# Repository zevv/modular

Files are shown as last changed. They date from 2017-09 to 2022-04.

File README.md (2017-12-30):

This repo contains the electronic design files and firmware for an
analog/digital hybrid modular synthesizer system. The synth will be built from
a collection of separate modules which can be connected (patched) like a
traditional modular synth. The modules contain a fast CPU and an audio codec
and perform all work in the digital domain. The same PCB design is used in all
modules, and the firmware will make each module behave as a different function
like oscillators, filters, wave shapers, delay, reverb, etc.

Engineering log with some pictures can be found here: http://zevv.nl/play/modular/

Some specs for the module so far:

* 204Mhz dual core ARM Cortex M4/M0
* 4 audio outputs 10v peak-to-peak at 10kΩ, 96kHz/24bit
* 4 audio inputs 10v peak-to-peak at 330Ω, 96kHz/24bit
* 8 generic inputs 10v peak-to-peak at 10kΩ, 12kHz/10 bit
* 12V power supply, internally split into +5/-5 volts 

My primary goal is to make a working setup for my personal use. However, if I'm
happy enough with the results and other people are interested, I might consider
manufacturing and selling modules at a small scale.

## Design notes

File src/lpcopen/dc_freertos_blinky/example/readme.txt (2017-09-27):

Blinky Example using Dual Core communication

Example description
This example blinks LED1 and LED2 at various rates, one of the LED
is turned on/off by M4 based on message received from M0. Meanwhile
M4 also sends blink message to M0 so that M0 core blinks the other LED.
LED1 will blink at the rate of 500ms/blink, LED2 will blink at the rate of
1s/blink.

This example is included by default in all other dual-core examples,
hence all the dual-core examples will blink LED1 and LED2.

*IMPORTANT NOTE:**
 
 M0 image boot failure will also cause (by default) LED2 to blink. This
 should not be confused with the Blinky task blinking the LED. The error
 blink will be at 20ms or 2s rate, the former rate indicates that the M0
 image loader code running on core-M4 could not locate a valid M0 image,
 whereas the latter rate indicates that a valid M0 image is found but its
 functionality is mutually exclusive with the functionalities of the image
 running in core-M4. In case of M0 boot error the blink will stop after 1
 minute.

Special connection requirements
   - Hitex LPC4350EVA-A4-2
      + LED1 is D10 (located below micro USB connector X9,*needs jumper JP3 closed**)
      + LED2 is RED of RGB LED
   - KEIL MCB4357
      + LED1 is PD_10 (located above push button P4_0)
      + LED2 is PD_11 (located next to LED1)
   - NGX Explorer4330
      + LED1 is D2 (Dull Green LED)
      + LED2 is D3 (Bright Blue LED)

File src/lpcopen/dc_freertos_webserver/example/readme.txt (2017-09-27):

HTTP server dual core example using lwIP ethernet stack

Example description
The LWIP HTTP Server example demonstrates the HTTP Server example using LWIP ethernet stack.
The HTTP server can be configured to run on any of the cores (M4 or M0).
The user should connect the board to the network by using the ethernet cable. The board will
get an IP address by using DHCP method. The use can access the HTTP Server by using a
web browser from the host PC.
If the USB Mass storage is compiled in the application (on either M0/M4 core), then it will
read the HTTP contents from USB Mass storage disk & provided to the user.
If the USB Mass storage is not compiled in the application (on either M0/M4 core), then the
default HTTP page will be displayed.
In FreeRTOS/uCOS-III configurations, the net_conn API interface will be used.
In stand-alone configuration, HTTPD interface will be used.

Special connection requirements
There are no special connection requirements for this example.

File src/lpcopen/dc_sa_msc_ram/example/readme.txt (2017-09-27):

This file contains a USB MSC RAM example using USB ROM Drivers.

Example description
The example shows how to use USBD ROM stack to creates a USB MSC example
that uses RAM.

Special connection requirements
Connect the USB cable between micro connector on board and to a host.
The example exposes part of internal SRAM as storage space.

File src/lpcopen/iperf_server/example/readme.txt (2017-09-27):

LWIP no-RTOS TCP Echo example

Example description
Welcome to the LWIP TCP Echo example using the raw API for standalone
without an RTOS) operation. This example shows how to use the raw API with
the LWIP contrib TCP Echo example using the 18xx/43xx LWIP MAC and PHY drivers.
The example shows how to handle PHY link monitoring and indicate to LWIP that
a ethernet cable is plugged in. It also shows how to manage input packet
handling and reclaim transmit pbufs once they are transmitted in the main
processing loop.

To use the example, Simply connect an ethernet cable to the board. The board
will acquire an IP address via DHCP and you can ping the board at it's IP
address. You can monitor network traffice to the board using a tool such as
wireshark at the boards MAC address.

Special connection requirements
There are no special connection requirements for this example.

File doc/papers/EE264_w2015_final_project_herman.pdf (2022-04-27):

# DSPFuzz A Guitar Distortion Pedal Using The Stanford DSP Sheild

Woody Herman
Center For Computer Research In Music And Acoustics Stanford University
Stanford, CA
Email: w.q.herman@gmail.com

Abstract—This project uses the Stanford DSP Sheild to implement a real time guitar distortion effects pedal. Presented here is a summary of the methods used, DSP concepts applied, and an analysis of what effects a distortion effect has on a signal.

I. INTRODUCTION

In live performance and in recording sessions, guitarists frequently alter the tone of their instrument using effects pedals, commonly referred to as stompboxes since the user engages the pedal with a foot swtich. One of the most widely used effects is the distortion, or overdrive, effect. This clips the signal of the guitar creating a unique distorted sound that can be heard on nearly every rock recording made since the 1950s. In its earliest from, distortion was implemented by driving the transistor or vacuum tube amplifiers used into cutoff. With the new prominence of digital recording and effects, many of the classic analog stompboxes have been implemented digitally with great effect. Distortion, however, remains firmly rooted in the analog domain. Because of the many nonlinearities present in these distortion effects, it has been hard to create pleasent sounding digital alternatives. Despite these issues, and because of the problems inherent in maintaining and designing analog equipment, developing quality digital versions would certainly be of great value. This project implements a simple and commonly used method for recreating distortion effects digitally.

II. OVERVIEW OF THE METHOD

A simple, commonly used technique for replicating the sound created by analog distortion pedals is to apply a predistortion filter, for controlling the input tone, follwed by up-sampling, applying the non-linearity, down sampling and finally another filter to control output tone. This technique is widley is used in industry and, if the tone filters are tuned properly and if the non-linearity is carefully chosen, can yeild sonically pleasing results. This method is primarily chosen for its compuational simplicity, many of the nonlinear functions (often called waveshaping functions) are polynomials relating input amplitude to output amplitude, and flexiblity to create a variety of sounds.

A. Waveshaping Functions
Choosing the waveshaping function that will clip the signal is a very subjective art, although there are several that have become very popular throughout the years. Generally, they all follow the same format. That is, they are non linear functions that relate input amplitude x to output amplitude y. Equations
(1) and (2) show two popular waveshaping functions.

y =

x
1 + |x|

(1)

y = x +

x

3
3

(2)

The functions above are written as they would be used for implementation in floating point systems. As will be shown later, fixed point arithmetic introdcues several new problems that make directly implementing these functions difficult if not impossible.

B. Tone Shaping Filters
Guitarists, and musicians in general, constantly talk about the tone of their instrument. The tone of an instrument in due in large part to the frequency response of that instrument. Because an electric guitar turns the vibration of its strings into electricity, we can apply any filter, analog or digital, that we might use in other applications. By boosting high frequencies we can make the guitar sound brighter, by boosting lower frequencies we can make the guitar sound fuller, or perhaps darker. What constitutes a good tone is highly subjective, but regardless of the result it is desireable to have some sort of filtering of the guitar signal in distortion effects. By applying a filter to the input and output signal of the effect, we can create custom tones or attempt to match the tone of famous analog effects.

III. RELATION TO COURSE TOPICS
Although the idea behind distortion is relatively simple, performing the operations digitally requires the use of a number of common and important digital signal processing theories. These include upsampling, digital filter design, analysis of our signal in the frequency domain, and fixed point arithmetic.

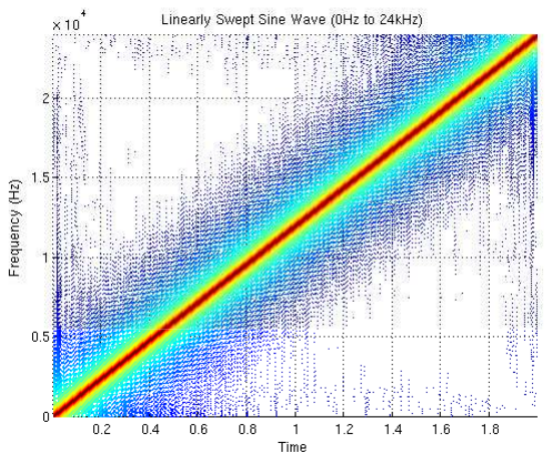
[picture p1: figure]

Fig. 1. Spectrogram of a chirp signal starting at dc and ending at 24kHz

A. Upsampling
As mentioned previously, implementing digital distortion requires the use of upsampling. This is because non linear functions, especially ones that clip the signal, introduce harmonics of the original frequency content. In distortion effects, when high gain is used, these harmonics can have audible amplitudes up to the 4th or 5th harmonic (that is 4 or 5 times the fundamental frequency). Because of this, we run the risk of our signal aliasing if a lot of distortion is applied. To counteract this aliasing, we upsample our signal to a much higher rate (8 and 16 are common factors used in industry) apply the non linearity and then down sample to the original rate. When used in conjunction with an interpolating and decimating filter, which can be the same filter since we are returning to the same sampling rate we started with, this blocks the aliased components while allowing for a natural expansion of harmonics in the audible range. This is important since the harmonics introduced by these clipping functions are an important part of the overall tone they give the guitar.
To illustrate this point, it is helpful to analyze the effects of clipping functions in the frequency domain using the DFT. Fig 1 shows a spectrogram of a chirp signal, a sine wave whose frequency increases linearly with time, that starts at dc and ends at the original nyquist frequency, 24kHz.
If we pass this chrip signal through a clipping function, then the effects of aliasing become apparent. Below is a figure showing the same chirp signal passed through a hard clipping function, where the signal is abruptly flattened at the maximum amplitude.
Fig. 2 is an exaggerated version of what might actually occur because the frequecny response of an electric guitar tends to roll off at higher frequencies. Nevertheless, aliasing is still audible when upsampling is not used. If upsampling is used in conjunction with an interpolating and decimating filter then we can remove the aliased components while preserving the desired harmonics that occur naturally in analog distortion devices.

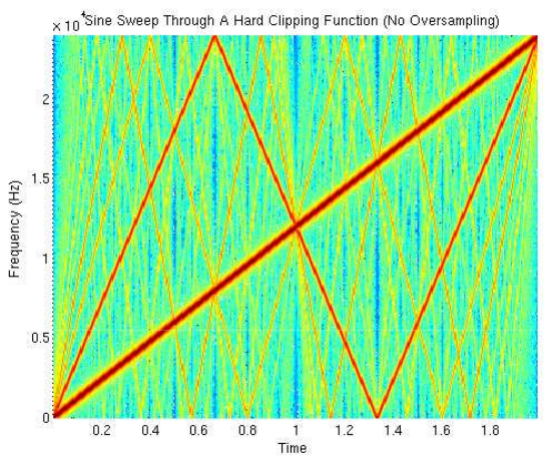
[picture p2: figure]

Fig. 2. Spectrogram of a chirp signal passed through a hard clipping function with no upsampling

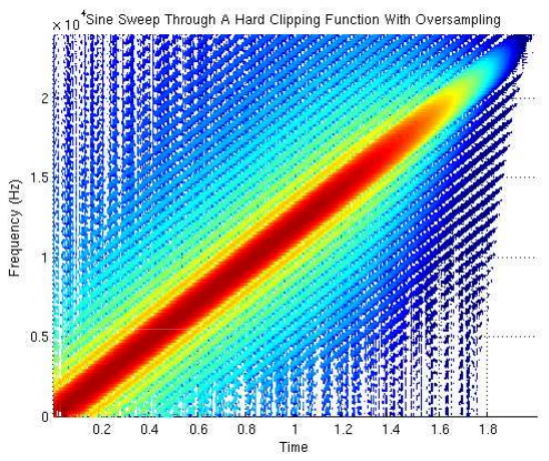
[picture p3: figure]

Fig. 3. Spectrogram of a chirp signal that has been upsampled by a factor of 8, filtered, clipped, filtered, and downsampled back to the original rate

Fig. 3 shows the same chirp signal passed through the same clipping function, but this time we have upsampled by a factor of 8 (using an interpolating filter whose design is described in subsequent sections), then applied the clipping function, then filtered the clipped signal with the same filter and downsampled back to the original rate. As can be seen in the plot, the aliased components have been removed but, as is desired, harmonics have been introduced to the signal. These harmonics are represented by the parallel bands in the spectrogram above and below the chirp signal. As mentioned before, these harmonics are very desireable since they help shape the tone of the disorted guitar signal. It should be noted that the magnitude of the chirp signal decreases as we approach nyquist. This, as will be shown later, is due to the fact that the filter used in upsampling and downsampling has a cutoff frequency below half the sampling rate.

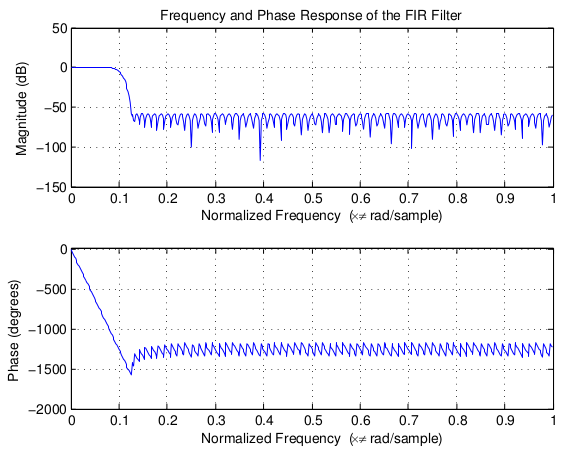
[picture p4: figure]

Fig. 4. Frequency response of the low pass filter used for up sampling and down sampling.

B. Filter Design

In order to properly implement the upsampling and downsampling required by digital distortion effects, we must design an interpolating filter that accomplishes several goals. First, as is always the case, it must remove the images of our spectrum created by sampling. Second, it must prevent aliasing caused by the non linear waveshaping function. Third, it must preserve as much of the original signal and added harmonics as possible. Lastly, it must be computationally efficient enough to be run in real time.
To accomplish the design criteria of the filter, the Parks-McLellan algorithm was used via MATLAB’s f irpm() function. Although a similar inerpolation and decimation filter could be acheived with a far lower order IIR filter, an FIR option is attractive for several reasons. Because the PM designed FIR filter would be linear phase, we know that no phase distortion would occur. Furthermore, the DSP Sheild has builtin functions in the DSP library that efficiently up sample and down sample using FIR filters. The library implementation of these functions would almost certainly be faster than anything written.
Figure 4 shows the frequency response of a 141 order Parks-McLellan designed filter. Because electric guitars typically have frequency responses that begin to roll off at a little over 10kHz we are able to have the filter pass band end at 15kHz with no real audible effects. This allows us to obtain a stop band gain of −60dB that begins at 24kHz which is 1
8

pi radians at the increased sampling rate. −60dB is a value commonly used in audio to represent when a signal has become inaudible. Thus, it is an appropriate stop band gain to acheive to successfully filter out any components that would alias at our original sampling rate.
The filter in fig. 4 is used in the program for both the upsampling and downsampling functions. This is possible because we are returning to the same sampling rate at which we began, thus the filter stop band must begin at the same

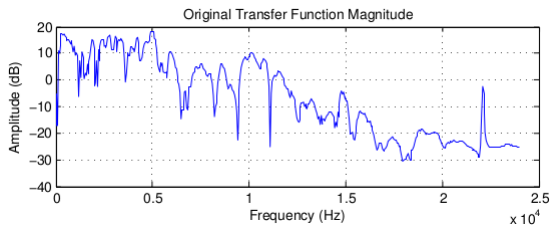
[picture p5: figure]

Fig. 5. Frequency response of a Vox ac30 guitar amplifier.

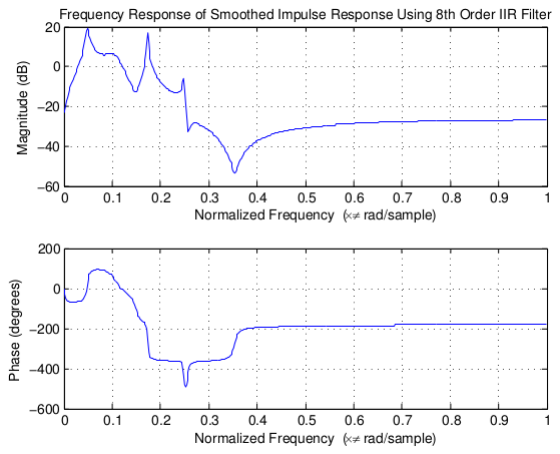
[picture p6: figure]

Fig. 6. 8th order approximation of the ac30 frequency response.

frequency in both cases.
In addition to the filtering required by upsampling and downsampling, it is also common to add filters that will change the tone of the guitar. The design of these filters, much like the design of the waveshaping functions, is very subjective. One common trick is to use impulse response measurements to try and mimic the tone of popular, vintage guitar amplifiers. Here, we can make use of the DSP Sheild’s hardware accelerated filters to alter the tone of the guitar without taking too much of a toll on the computational efficiency of the effect. Impulse responses of many of the most popular guitar amplifiers are freely available online. By taking the DFT of the impulse response of the Vox ac30 amplifier, a very popular vintage vaccuum tube amplifier, we can obtain the frequency response shown in fig. 5.
Using MATLAB’s invfreqz() function, we can model the frequency response with a desired filter order. Using an eigth order filter, we can get the frequency and phase response shown in fig. 6.
Although this may not be the most accurate model, it still encompasses some of the major features (blocking dc, boost in the lower-middle frequencies, and a tapering off in the higher frequenices), and should provide an interesting filter to shape the tone of the pedal. By breaking the 8th order filter into second order sections and quantizing the coefficients, we can implement this filter using the DSP Sheild’s hardware accelerated filters on the ADC and DAC.
C. Fixed Point Waveshaping Functions
Waveshaping functions are often used to implement digital distortion because of their simplicity and computational efficiency. This line of thought is very true in floating point systems. However, as we have seen throughout the quarter, fixed point architectures tend to make things a little more difficult. Two observations can be made by examining equations (1) and (2). We can note that (1) requires a division at every sample to compute. Division is an expensive operation, especially in a fixed point system where the division is happening at an oversampled rate. In fact, division is such an expensive operation to perform that running the program using the waveshaping equation in (1) is impossible.
Equation (2) presents its own challenges. As it is written,
(2) clips a signal in the range −1 ≤ x ≤ 1. However, because we are operating in a fixed point system, we want to clip a signal in the range −32768 ≤ x ≤ 32768. To accomplish this we must re-arrange (2) to the following:

y = x +

x
32768² ∗ 3

(3)

Equation (3) also requires a division but, because it is a constant, it could be precomputed and used as a multiplication. However, because the number in the denominator is so large, the scaling factor required in the equation would be a number that is smaller than the smallest possible number that can be represented with 15 bits, and it is very close to the smallest number that can be represented with 31 bits. Therefore, implementing this with 15 bits as the base number of bits would be very difficult if not impossible. The way to get around this is to use a lookup table, a set of points sampled from the curve created by eq. (3) and then joined by together by linear interpolation. If enough points are used, then the lookup table can closely approximate the curve generated by eq. (3). The use of lookup tables to approximate nonlinear curves is common among digital distoriton effects, and it is the process that is used here.

IV. PROPOSED VS ORIGINAL TIMELINE
The original proposed timeline was largely followed, although it was accelerated slightly. Some components, as per the feedback, were left until the end after more important components had been implemented.
A. Weeks One and Two
Weeks one and two, in the original proposal, were designated as basic set up weeks. They were intended to establish basic connections to the board for the guitar. This involved passing a guitar signal, via a 1
4

inch. cable commonly used for guitars, to the DSP Sheild and then out to a guitar amplifier. Another connection that would be established in the first two weeks would be to connect the potentiometers that would control the volume and amount of distortion. Additionally, it was intended that a box to house the DSP Sheild would be constructed in the first two weeks.

As suggested by the comments, several of the goals of weeks one and two were shifted to the end of the project. Building a housing for the pedal, and attaching the pentiometers were determined to be additional components but not essential to the main objective of the project. Therefore, during week one, the guitar was successfully passed through the dsp sheild and out to an amplifier. Upsampling and downsampling, including the design of the filter used in each case, was also accomplished in the first two weeks. Towards the end of week two, work was begun to implement the non linear function, although this was not successfully implemented until the beginning of week 3.

B. Weeks Three and Four
Originally, weeks three and four would be used for designing tone filters, adding upsampling and implementing the non linearity. Because it was decided that these features were more important than some of the ones originally intended to be implemented in weeks one and two (potentiometers and case for the pedal); weeks three and four were left for the optional components.
At the beginning of week three, the non linearity was finished, thus completeing the bare essentials of the distortion effect. The tone filters were designed and implemented using the hardware accelerators in this week. This left the rest of week three and week four to implement the optional components, such as constructing the case and attatching the potentiometers.
V. CONCLUSIONS AND FUTURE WORK
Digital audio effects are an ever groing presence in modern music making. In order to make commercially viable, portable products (ones that do not need to be run on a full pc), fixed point dsp processors will continue to be used for the forseeable future. Having an affordable, well documented, easily programmable learning tool to implement these effects is invaluable. In addition, the DSP Sheild can be used as a prototyping tool for novel effects. I plan on keeping the DSP Sheild to use as both a learning tool and as a tool to implement original effects in an easy to program format. Becuase I have already built the basic structure of a guitar pedal, it is a simple matter of replacing the code on the sim card of the DSP Sheild to test out and implement a variety of effects.

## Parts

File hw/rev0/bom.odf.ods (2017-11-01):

Id | Designator | Package | Quantity | Designation | Farnell # |  | 5
1 | J14 | USB_Micro-B_Molex-105017-0001 | 1 | USB_OTG | 2293836 |  | 5
2 | L4,L8,L9,L7,L6,L2,L1,L3 | L_0805 | 8 | Ferrite | 1515661 |  | 40
3 | U1 | LQFP-144_20x20mm_Pitch0.5mm | 1 | LPC4330FBD144 | 2094316 |  | 5
4 | C10,C39,C11,C19,C12,C2,C1,C3,C4,C6,C7,C8,C9,C5,C21,C40 | C_0603 | 16 | 100nF | 2522597 |  | 80
5 | J12,J16,J9,J6,J10,J3,J2,J7,J5,J13,J15,J4 | modularctl2 | 12 | Conn_01x04 | ### |  | 60
6 | R38,R99,R98,R39,R96,R97,R21,R18,R6,R52,R22,R20,R3,R36,R37,R53,R54,R55,R8,R10,R13,R15,R68,R69,R80,R81,R109,R24 | R_0603 | 28 | 10k | 2446547 |  | 140
7 | J19,J17,J18,J20 | Pin_Header_Straight_1x01_Pitch1.27mm | 4 | GND | ### |  | 20
8 | U2,U15 | SOT-223-3Lead_TabPin2 | 2 | LD1117S33TR_SOT223 | 1202826 |  | 10
9 | C18,C27,C28,C31,C32,C22,C57,C63 | C_0805 | 8 | 10uF | 2497048 |  | 40
10 | TP17,TP28,TP29,TP13,TP24,TP15,TP3,TP6,TP5,TP16,TP4,TP2,TP9,TP21,TP20,TP14,TP12,TP11,TP10,TP8,TP7,TP1,TP18,TP19,TP25,TP22,TP23,TP26,TP27,TP30,TP31,TP32,TP33,TP34,TP35,TP36,TP37,TP38,TP39,TP40,TP41 | Measurement_Point_Round-SMD-Pad_Small | 41 | TEST | ### |  | 205
11 | U11,U5,U6,U7,U8,U9,U10,U12,U16 | SOIC-8_3.9x4.9mm_Pitch1.27mm | 9 | TL972 | 1755226 |  | 45
12 | R56,R57,R58,R59,R19,R23,R25 | R_0603 | 4 | 330R | 2073475 |  | 20
13 | R94,R92,R32,R34,R88,R90,R50,R48,R66,R64,R62,R60,R30,R28,R76,R78 | R_0603 | 16 | 2k49 | 1170826 |  | 80
14 | R103,R102,R42,R43,R100,R101,R40,R41,R70,R71,R72,R73,R74,R75,R82,R83,R49 | R_0603 | 17 | 3k3 | 2447359 |  | 85
15 | R107,R106,R47,R46,R104,R105,R45,R44,R84,R85,R86,R87 | R_0603 | 12 | 100r | 2447227 |  | 60
16 | R33 | R_0603 | 1 | N.P. | ### | N.P. | 5
17 | C49,C50,C41,C42,C43,C44,C51,C52 | C_0603 | 8 | 4.7nF | 1759098 |  | 40
18 | SW3 | SW_DIP_x6_W6.15mm_Slide_Omron_A6H | 1 | SW_DIP_x06 | 8774277 |  | 5
19 | J11,J8 | IDC_Header_Straight_12pins | 2 | Conn_02x06_Odd_Even | ### |  | 10
20 | R4,R5,R2,R1 | R_0603 | 7 | 18k | 9331875 | mag 10K | 35
21 | U13 | SO-8_5.3x6.2mm_Pitch1.27mm | 1 | AT45DB161-E | ### |  | 5
22 | L5 | R_0603 | 1 | Ferrite | ### |  | 5
23 | D3,D4,D5 | LED_0805 | 3 | LED | x / x / x | handmatig | 15
24 | J1 | Pin_Header_Straight_1x03_Pitch2.54mm | 1 | Debug UART | ### |  | 5
25 | U3,U4 | LFCSP20 | 2 | SSM2604 | 2457480 |  | 10
26 | C34,C36,C35,C33,C30,C29 | C_0603 | 6 | 0.1uF | 2522597 |  | 30
27 | C38,C37 | C_0805 | 2 | 4.7uF | 2496930 |  | 10
28 | Y2,Y3 | Crystal_SMD_Abracon_ABM3B-4pin_5.0x3.2mm | 2 | Crystal_GND24 | 1611810 | N.P. | 10
29 | Y1 | Crystal_SMD_Abracon_ABM3B-4pin_5.0x3.2mm | 1 | 12MHz | 1611810 |  | 5
30 | C26,C25,C23,C24 | C_0603 | 4 | 22pF | 1759057 | N.P. | 20
31 | R17 | R_0603 | 1 | 120r | 9238379 |  | 5
32 | R27,R26 | R_0603 | 2 | 15k | 2447256 |  | 10
33 | C17,C16 | C_0603 | 2 | 18pF | 2496890 |  | 10
34 | C14,C15 | C_0603 | 2 | 10nF | 2522596 |  | 10
35 | C13 | C_0603 | 1 | 1nF |  |  | 5
36 | D1,D2 | D_0805 | 2 | D | 2708389 | 0R | 10
37 | R7,R11,R14,R16 | R_0603 | 4 | NM | #### |  | 20
38 | R108 | R_0603 | 1 | 100k | use 10k | mag 10K | 5
39 | U14 | SOIC-8_3.9x4.9mm_Pitch1.27mm | 1 | SN65HVD231 | 1106059 |  | 5
40 | SW1,SW2 | SW_SPST_EVQPE1 | 2 | SW_Push | #### | handmatig | 10
41 | C59,C60,C61,C62 | C_0603 | 4 | N.P. | #### | N.P. | 20
42 | R35 | R_0603 | 1 | 5k6 | 2447405 |  | 5

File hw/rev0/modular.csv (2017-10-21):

Id | Designator | Package | Quantity | Designation | Supplier and ref
1 | J14 | USB_Micro-B_Molex-105017-0001 | 1 | USB_OTG
2 | L4,L8,L9,L7,L6,L2,L1,L3 | L_0805 | 8 | Ferrite
3 | U1 | LQFP-144_20x20mm_Pitch0.5mm | 1 | LPC4330FBD144
4 | C10,C39,C11,C19,C12,C2,C1,C3,C4,C6,C7,C8,C9,C5,C21,C40 | C_0603 | 16 | 100nF
5 | J12,J16,J9,J6,J10,J3,J2,J7,J5,J13,J15,J4 | modularctl2 | 12 | Conn_01x04
6 | R38,R99,R98,R39,R96,R97,R21,R18,R6,R52,R22,R20,R3,R36,R37,R53,R54,R55,R8,R10,R13,R15,R68,R69,R80,R81,R109,R24 | R_0603 | 28 | 10k
7 | J19,J17,J18,J20 | Pin_Header_Straight_1x01_Pitch1.27mm | 4 | GND
8 | U2,U15 | SOT-223-3Lead_TabPin2 | 2 | LD1117S33TR_SOT223
9 | C18,C27,C28,C31,C32,C22,C57,C63 | C_0805 | 8 | 10uF
10 | TP17,TP28,TP29,TP13,TP24,TP15,TP3,TP6,TP5,TP16,TP4,TP2,TP9,TP21,TP20,TP14,TP12,TP11,TP10,TP8,TP7,TP1,TP18,TP19,TP25,TP22,TP23,TP26,TP27,TP30,TP31,TP32,TP33,TP34,TP35,TP36,TP37,TP38,TP39,TP40,TP41 | Measurement_Point_Round-SMD-Pad_Small | 41 | TEST
11 | U11,U5,U6,U7,U8,U9,U10,U12,U16 | SOIC-8_3.9x4.9mm_Pitch1.27mm | 9 | TL972
12 | R56,R57,R58,R59 | R_0603 | 4 | 330R
13 | R94,R92,R32,R34,R88,R90,R50,R48,R66,R64,R62,R60,R30,R28,R76,R78 | R_0603 | 16 | 2k49
14 | R103,R102,R42,R43,R100,R101,R40,R41,R70,R71,R72,R73,R74,R75,R82,R83,R49 | R_0603 | 17 | 3k3
15 | R107,R106,R47,R46,R104,R105,R45,R44,R84,R85,R86,R87 | R_0603 | 12 | 100r
16 | R33 | R_0603 | 1 | N.P.
17 | C49,C50,C41,C42,C43,C44,C51,C52 | C_0603 | 8 | 4.7nF
18 | SW3 | SW_DIP_x6_W6.15mm_Slide_Omron_A6H | 1 | SW_DIP_x06
19 | J11,J8 | IDC_Header_Straight_12pins | 2 | Conn_02x06_Odd_Even
20 | R25,R23,R19,R4,R5,R2,R1 | R_0603 | 7 | 18k
21 | U13 | SO-8_5.3x6.2mm_Pitch1.27mm | 1 | AT45DB161-E
22 | L5 | R_0603 | 1 | Ferrite
23 | D3,D4,D5 | LED_0805 | 3 | LED
24 | J1 | Pin_Header_Straight_1x03_Pitch2.54mm | 1 | Debug UART
25 | U3,U4 | LFCSP20 | 2 | SSM2604
26 | C34,C36,C35,C33,C30,C29 | C_0603 | 6 | 0.1uF
27 | C38,C37 | C_0805 | 2 | 4.7uF
28 | Y2,Y3 | Crystal_SMD_Abracon_ABM3B-4pin_5.0x3.2mm | 2 | Crystal_GND24
29 | Y1 | Crystal_SMD_Abracon_ABM3B-4pin_5.0x3.2mm | 1 | 12MHz
30 | C26,C25,C23,C24 | C_0603 | 4 | 22pF
31 | R17 | R_0603 | 1 | 120r
32 | R27,R26 | R_0603 | 2 | 15k
33 | C17,C16 | C_0603 | 2 | 18pF
34 | C14,C15 | C_0603 | 2 | 10nF
35 | C13 | C_0603 | 1 | 1nF
36 | D1,D2 | D_0805 | 2 | D
37 | R7,R11,R14,R16 | R_0603 | 4 | NM
38 | R108 | R_0603 | 1 | 100k
39 | U14 | SOIC-8_3.9x4.9mm_Pitch1.27mm | 1 | SN65HVD231
40 | SW1,SW2 | SW_SPST_EVQPE1 | 2 | SW_Push
41 | C59,C60,C61,C62 | C_0603 | 4 | N.P.
42 | R35 | R_0603 | 1 | 5k6

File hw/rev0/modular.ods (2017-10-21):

Id | Designator | Package | Quantity | Designation | Supplier and ref | 20
1 | J14 | USB_Micro-B_Molex-105017-0001 | 1 | USB_OTG | 2293836 | 20
2 | L4,L8,L9,L7,L6,L2,L1,L3 | L_0805 | 8 | Ferrite |  | 160
3 | U1 | LQFP-144_20x20mm_Pitch0.5mm | 1 | LPC4330FBD144 |  | 20
4 | C10,C39,C11,C19,C12,C2,C1,C3,C4,C6,C7,C8,C9,C5,C21,C40 | C_0603 | 16 | 100nF |  | 320
5 | J12,J16,J9,J6,J10,J3,J2,J7,J5,J13,J15,J4 | modularctl2 | 12 | Conn_01x04 |  | 240
6 | R38,R99,R98,R39,R96,R97,R21,R18,R6,R52,R22,R20,R3,R36,R37,R53,R54,R55,R8,R10,R13,R15,R68,R69,R80,R81,R109,R24 | R_0603 | 28 | 10k |  | 560
7 | J19,J17,J18,J20 | Pin_Header_Straight_1x01_Pitch1.27mm | 4 | GND |  | 240
8 | U2,U15 | SOT-223-3Lead_TabPin2 | 2 | LD1117S33TR_SOT223 |  | 40
9 | C18,C27,C28,C31,C32,C22,C57,C63 | C_0805 | 8 | 10uF |  | 240
10 | TP17,TP28,TP29,TP13,TP24,TP15,TP3,TP6,TP5,TP16,TP4,TP2,TP9,TP21,TP20,TP14,TP12,TP11,TP10,TP8,TP7,TP1,TP18,TP19,TP25,TP22,TP23,TP26,TP27,TP30,TP31,TP32,TP33,TP34,TP35,TP36,TP37,TP38,TP39,TP40,TP41 | Measurement_Point_Round-SMD-Pad_Small | 41 | TEST |  | 240
11 | U11,U5,U6,U7,U8,U9,U10,U12,U16 | SOIC-8_3.9x4.9mm_Pitch1.27mm | 9 | TL972 |  | 240
12 | R56,R57,R58,R59 | R_0603 | 4 | 330R |  | 240
13 | R94,R92,R32,R34,R88,R90,R50,R48,R66,R64,R62,R60,R30,R28,R76,R78 | R_0603 | 16 | 2k49 |  | 240
14 | R103,R102,R42,R43,R100,R101,R40,R41,R70,R71,R72,R73,R74,R75,R82,R83,R49 | R_0603 | 17 | 3k3 |  | 240
15 | R107,R106,R47,R46,R104,R105,R45,R44,R84,R85,R86,R87 | R_0603 | 12 | 100r |  | 240
16 | R33 | R_0603 | 1 | N.P. |  | 240
17 | C49,C50,C41,C42,C43,C44,C51,C52 | C_0603 | 8 | 4.7nF |  | 240
18 | SW3 | SW_DIP_x6_W6.15mm_Slide_Omron_A6H | 1 | SW_DIP_x06 |  | 240
19 | J11,J8 | IDC_Header_Straight_12pins | 2 | Conn_02x06_Odd_Even |  | 240
20 | R25,R23,R19,R4,R5,R2,R1 | R_0603 | 7 | 18k |  | 20
21 | U13 | SO-8_5.3x6.2mm_Pitch1.27mm | 1 | AT45DB161-E |  | 20
22 | L5 | R_0603 | 1 | Ferrite |  | 20
23 | D3,D4,D5 | LED_0805 | 3 | LED |  | 20
24 | J1 | Pin_Header_Straight_1x03_Pitch2.54mm | 1 | Debug UART |  | 20
25 | U3,U4 | LFCSP20 | 2 | SSM2604 |  | 20
26 | C34,C36,C35,C33,C30,C29 | C_0603 | 6 | 0.1uF |  | 20
27 | C38,C37 | C_0805 | 2 | 4.7uF |  | 20
28 | Y2,Y3 | Crystal_SMD_Abracon_ABM3B-4pin_5.0x3.2mm | 2 | Crystal_GND24 |  | 20
29 | Y1 | Crystal_SMD_Abracon_ABM3B-4pin_5.0x3.2mm | 1 | 12MHz |  | 20
30 | C26,C25,C23,C24 | C_0603 | 4 | 22pF |  | 20
31 | R17 | R_0603 | 1 | 120r |  | 20
32 | R27,R26 | R_0603 | 2 | 15k |  | 20
33 | C17,C16 | C_0603 | 2 | 18pF |  | 20
34 | C14,C15 | C_0603 | 2 | 10nF |  | 20
35 | C13 | C_0603 | 1 | 1nF |  | 20
36 | D1,D2 | D_0805 | 2 | D |  | 20
37 | R7,R11,R14,R16 | R_0603 | 4 | NM |  | 20
38 | R108 | R_0603 | 1 | 100k |  | 20
39 | U14 | SOIC-8_3.9x4.9mm_Pitch1.27mm | 1 | SN65HVD231 |  | 20
40 | SW1,SW2 | SW_SPST_EVQPE1 | 2 | SW_Push |  | 20
41 | C59,C60,C61,C62 | C_0603 | 4 | N.P. |  | 20
42 | R35 | R_0603 | 1 | 5k6 |  | 20

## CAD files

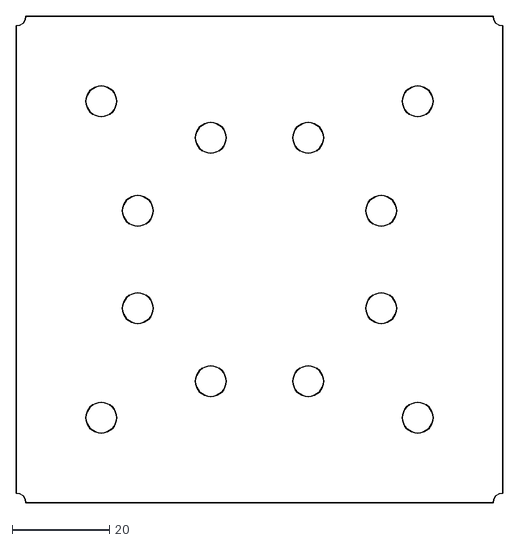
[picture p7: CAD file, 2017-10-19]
design/panel-metaal.dxf
100.0 x 100.0

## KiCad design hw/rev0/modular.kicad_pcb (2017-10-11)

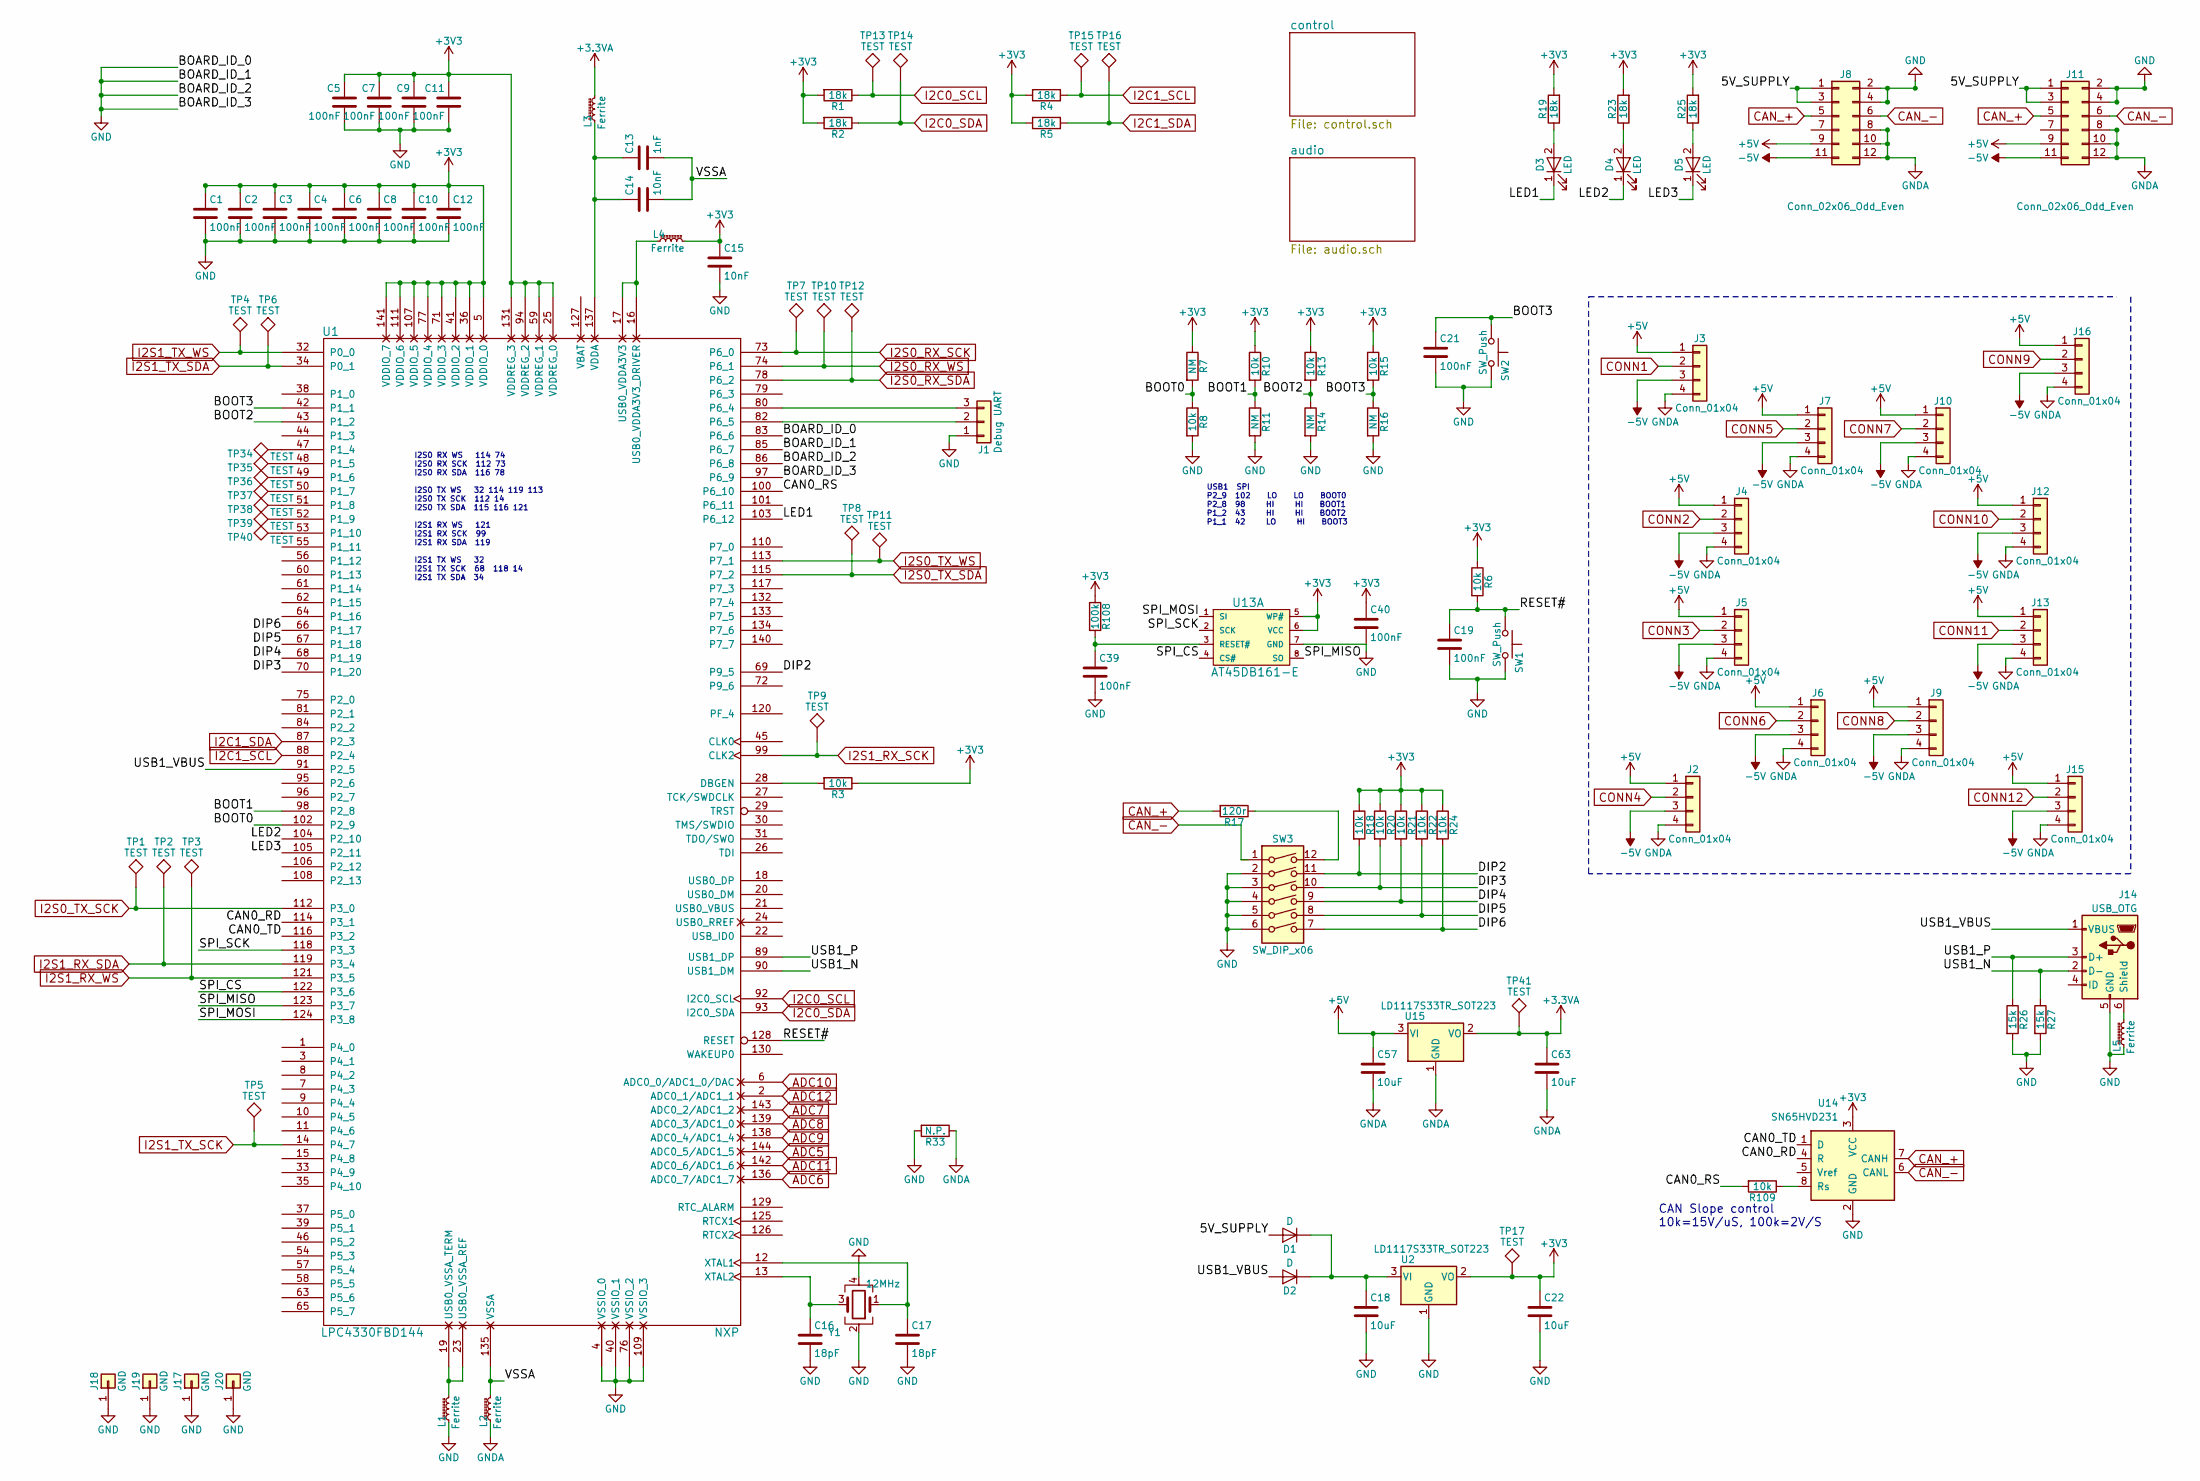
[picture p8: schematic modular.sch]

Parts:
C1, C2, C3, C4, C5, C6, C7, C8, C9, C10, C11, C12, C19, C21, C39, C40: 100nF; C_0603
C13: 1nF; C_0603
C14, C15: 10nF; C_0603
C16, C17: 18pF; C_0603
C18, C22, C57, C63: 10uF; C_0805
D1, D2: D; D_0805
D3, D4, D5: LED; LED_0805
J1: Debug UART; Pin_Header_Straight_1x03_Pitch2.54mm
J2, J3, J4, J5, J6, J7, J9, J10, J12, J13, J15, J16: Conn_01x04; modularctl2
J8, J11: Conn_02x06_Odd_Even; IDC_Header_Straight_12pins
J14: USB_OTG; USB_Micro-B_Molex-105017-0001
J17, J18, J19, J20: GND; Pin_Header_Straight_1x01_Pitch1.27mm
L1, L2, L3, L4: Ferrite; L_0805
L5: Ferrite; R_0603
R1, R2, R4, R5, R19, R23, R25: 18k; R_0603
R3, R6, R8, R10, R13, R15, R18, R20, R21, R22, R24, R109: 10k; R_0603
R7, R11, R14, R16: NM; R_0603
R17: 120r; R_0603
R26, R27: 15k; R_0603
R33: N.P.; R_0603
R108: 100k; R_0603
SW1, SW2: SW_Push; SW_SPST_EVQPE1
SW3: SW_DIP_x06; SW_DIP_x6_W6.15mm_Slide_Omron_A6H
TP1, TP2, TP3, TP4, TP5, TP6, TP7, TP8, TP9, TP10, TP11, TP12, TP13, TP14, TP15, TP16, TP17, TP34, TP35, TP36, TP37, TP38, TP39, TP40, TP41: TEST; Measurement_Point_Round-SMD-Pad_Small
U1: LPC4330FBD144; LQFP-144_20x20mm_Pitch0.5mm
U2, U15: LD1117S33TR_SOT223; SOT-223-3Lead_TabPin2
U13: AT45DB161-E; SO-8_5.3x6.2mm_Pitch1.27mm
U14: SN65HVD231; SOIC-8_3.9x4.9mm_Pitch1.27mm
Y1: 12MHz; Crystal_SMD_Abracon_ABM3B-4pin_5.0x3.2mm

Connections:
+3.3VA: C63.1, L3.2, TP41.1, U15.2 (VO); also elsewhere on the board
+3V3: C1.1, C2.1, C3.1, C4.1, C5.1, C6.1, C7.1, C8.1, C9.1, C10.1, C11.1, C12.1, C15.1, C22.1, C40.1, L4.2, R1.2, R2.2, R3.1, R4.2, R5.2, R6.1, R7.1, R10.1, R13.1, R15.1, R18.1, R19.2, R20.1, R21.1, R22.1, R23.2, R24.1, R25.2, R108.1, TP17.1, U1.5 (VDDIO_0), U1.25 (VDDREG_0), U1.36 (VDDIO_1), U1.41 (VDDIO_2), U1.59 (VDDREG_1), U1.71 (VDDIO_3), U1.77 (VDDIO_4), U1.94 (VDDREG_2), U1.107 (VDDIO_5), U1.111 (VDDIO_6), U1.131 (VDDREG_3), U1.141 (VDDIO_7), U2.2 (VO), U13.5 (WP#), U13.6 (VCC), U14.3 (VCC); also elsewhere on the board
+5V: C57.1, J2.1, J3.1, J4.1, J5.1, J6.1, J7.1, J8.9, J9.1, J10.1, J11.9, J12.1, J13.1, J15.1, J16.1, U15.3 (VI); also elsewhere on the board
-5V: J2.3, J3.3, J4.3, J5.3, J6.3, J7.3, J8.11, J9.3, J10.3, J11.11, J12.3, J13.3, J15.3, J16.3; also elsewhere on the board
/5V_SUPPLY: D1.2 (A), J8.1, J8.3, J11.1, J11.3
/BOOT0: R7.2, R8.1, U1.102 (P2_9)
/BOOT1: R10.2, R11.1, U1.98 (P2_8)
/BOOT2: R13.2, R14.1, U1.43 (P1_2)
/BOOT3: C21.1, R15.2, R16.1, SW2.1, U1.42 (P1_1)
/CAN0_RD: U1.114 (P3_1), U14.4 (R)
/CAN0_RS: R109.2, U1.100 (P6_10)
/CAN0_TD: U1.116 (P3_2), U14.1 (D)
/DIP2: R18.2, SW3.11, U1.69 (P9_5)
/DIP3: R20.2, SW3.10, U1.70 (P1_20)
/DIP4: R21.2, SW3.9, U1.68 (P1_19)
/DIP5: R22.2, SW3.8, U1.67 (P1_18)
/DIP6: R24.2, SW3.7, U1.66 (P1_17)
/LED1: D3.1 (K), U1.103 (P6_12)
/LED2: D4.1 (K), U1.104 (P2_10)
/LED3: D5.1 (K), U1.105 (P2_11)
/RESET#: C19.1, R6.2, SW1.1, U1.128 (RESET)
/SPI_CS: U1.122 (P3_6), U13.4 (CS#)
/SPI_MISO: U1.123 (P3_7), U13.8 (SO)
/SPI_MOSI: U1.124 (P3_8), U13.1 (SI)
/SPI_SCK: U1.118 (P3_3), U13.2 (SCK)
/USB1_N: J14.2 (D-), R27.1, U1.90 (USB1_DM)
/USB1_P: J14.3 (D+), R26.1, U1.89 (USB1_DP)
/USB1_VBUS: D2.2 (A), J14.1 (VBUS), U1.91 (P2_5)
/VSSA: C13.2, C14.2, L2.2, U1.135 (VSSA)
ADC5: U1.144 (ADC0_5/ADC1_5); also elsewhere on the board
ADC6: U1.136 (ADC0_7/ADC1_7); also elsewhere on the board
ADC7: U1.143 (ADC0_2/ADC1_2); also elsewhere on the board
ADC8: U1.139 (ADC0_3/ADC1_0); also elsewhere on the board
ADC9: U1.138 (ADC0_4/ADC1_4); also elsewhere on the board
ADC10: U1.6 (ADC0_0/ADC1_0/DAC); also elsewhere on the board
ADC11: U1.142 (ADC0_6/ADC1_6); also elsewhere on the board
ADC12: U1.2 (ADC0_1/ADC1_1); also elsewhere on the board
CAN_+: J8.5, J11.5, R17.2, U14.7 (CANH)
CAN_-: J8.6, J11.6, SW3.1, U14.6 (CANL)
CONN1: J3.2; also elsewhere on the board
CONN2: J4.2; also elsewhere on the board
CONN3: J5.2; also elsewhere on the board
CONN4: J2.2; also elsewhere on the board
CONN5: J7.2; also elsewhere on the board
CONN6: J6.2; also elsewhere on the board
CONN7: J10.2; also elsewhere on the board
CONN8: J9.2; also elsewhere on the board
CONN9: J16.2; also elsewhere on the board
CONN10: J12.2; also elsewhere on the board
CONN11: J13.2; also elsewhere on the board
CONN12: J15.2; also elsewhere on the board
GNDA: C57.2, C63.2, J2.4, J3.4, J4.4, J5.4, J6.4, J7.4, J8.8, J8.10, J8.12, J9.4, J10.4, J11.8, J11.10, J11.12, J12.4, J13.4, J15.4, J16.4, L2.1, R33.1, U15.1 (GND); also elsewhere on the board
I2C0_SCL: R1.1, TP13.1, U1.92 (I2C0_SCL); also elsewhere on the board
I2C0_SDA: R2.1, TP14.1, U1.93 (I2C0_SDA); also elsewhere on the board
I2C1_SCL: R4.1, TP15.1, U1.88 (P2_4); also elsewhere on the board
I2C1_SDA: R5.1, TP16.1, U1.87 (P2_3); also elsewhere on the board
I2S0_RX_SCK: TP7.1, U1.73 (P6_0); also elsewhere on the board
I2S0_RX_SDA: TP12.1, U1.78 (P6_2); also elsewhere on the board
I2S0_RX_WS: TP10.1, U1.74 (P6_1); also elsewhere on the board
I2S0_TX_SCK: TP1.1, U1.112 (P3_0)
I2S0_TX_SDA: TP8.1, U1.115 (P7_2); also elsewhere on the board
I2S0_TX_WS: TP11.1, U1.113 (P7_1); also elsewhere on the board
I2S1_RX_SCK: TP9.1, U1.99 (CLK2); also elsewhere on the board
I2S1_RX_SDA: TP2.1, U1.119 (P3_4); also elsewhere on the board
I2S1_RX_WS: TP3.1, U1.121 (P3_5); also elsewhere on the board
I2S1_TX_SCK: TP5.1, U1.14 (P4_7)
I2S1_TX_SDA: TP6.1, U1.34 (P0_1); also elsewhere on the board
I2S1_TX_WS: TP4.1, U1.32 (P0_0); also elsewhere on the board
unnamed: C13.1, C14.1, L3.1, U1.137 (VDDA)
unnamed: C16.1, U1.13 (XTAL2), Y1.3
unnamed: C18.1, D1.1 (K), D2.1 (K), U2.3 (VI)
unnamed: C39.1, R108.2, U13.3 (RESET#)
unnamed: D3.2 (A), R19.1
unnamed: D4.2 (A), R23.1
unnamed: D5.2 (A), R25.1
unnamed: J1.2, U1.82 (P6_5)
unnamed: J1.3, U1.80 (P6_4)
unnamed: J14.6 (Shield), L5.2
unnamed: L1.2, U1.19 (USB0_VSSA_TERM), U1.23 (USB0_VSSA_REF)
unnamed: L4.1, U1.16 (USB0_VDDA3V3_DRIVER), U1.17 (USB0_VDDA3V3)
unnamed: R3.2, U1.28 (DBGEN)
unnamed: R17.1, SW3.12
unnamed: R109.1, U14.8 (Rs)
unnamed: TP34.1, U1.47 (P1_4)
unnamed: TP35.1, U1.48 (P1_5)
unnamed: TP36.1, U1.49 (P1_6)
unnamed: TP37.1, U1.50 (P1_7)
unnamed: TP38.1, U1.51 (P1_8)
unnamed: TP39.1, U1.52 (P1_9)
unnamed: TP40.1, U1.53 (P1_10)

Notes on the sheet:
I2S0 RX WS 114 74 I2S0 RX SCK 112 73 I2S0 RX SDA 116 78 I2S0 TX WS 32 114 119 113 I2S0 TX SCK 112 14 I2S0 TX SDA 115 116 121 I2S1 RX WS 121 I2S1 RX SCK 99 I2S1 RX SDA 119 I2S1 TX WS 32 I2S1 TX SCK 68 118 14 I2S1 TX SDA 34
USB1 SPI P2_9 102 LO LO BOOT0 P2_8 98 HI HI BOOT1 P1_2 43 HI HI BOOT2 P1_1 42 LO HI BOOT3
CAN Slope control 10k=15V/uS, 100k=2V/S

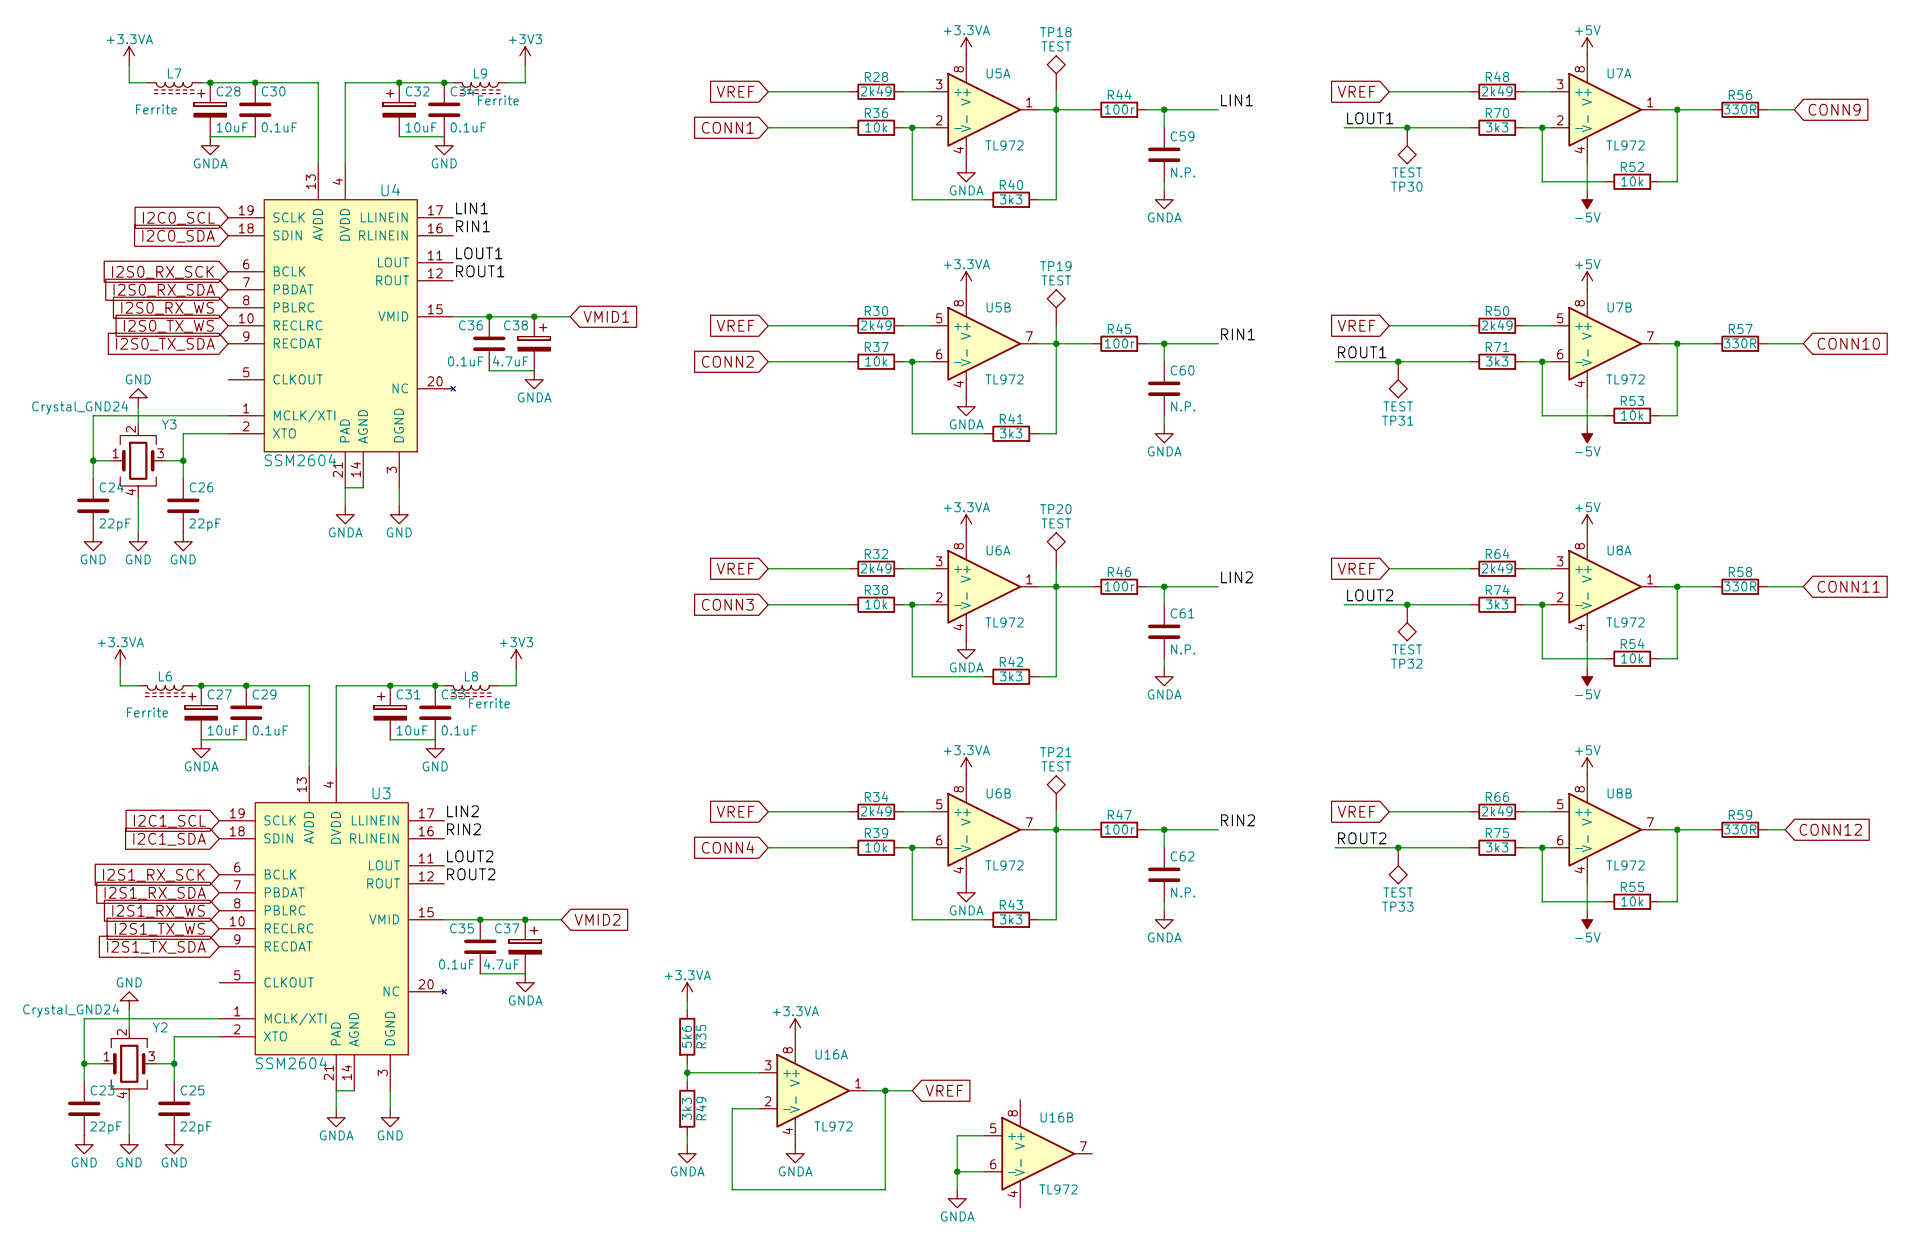
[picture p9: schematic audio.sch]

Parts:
C23, C24, C25, C26: 22pF; C_0603
C27, C28, C31, C32: 10uF; C_0805
C29, C30, C33, C34, C35, C36: 0.1uF; C_0603
C37, C38: 4.7uF; C_0805
C59, C60, C61, C62: N.P.; C_0603
L6, L7, L8, L9: Ferrite; L_0805
R28, R30, R32, R34, R48, R50, R64, R66: 2k49; R_0603
R35: 5k6; R_0603
R36, R37, R38, R39, R52, R53, R54, R55: 10k; R_0603
R40, R41, R42, R43, R49, R70, R71, R74, R75: 3k3; R_0603
R44, R45, R46, R47: 100r; R_0603
R56, R57, R58, R59: 330R; R_0603
TP18, TP19, TP20, TP21, TP30, TP31, TP32, TP33: TEST; Measurement_Point_Round-SMD-Pad_Small
U3, U4: SSM2604; LFCSP20
U5, U6, U7, U8, U16: TL972; SOIC-8_3.9x4.9mm_Pitch1.27mm
Y2, Y3: Crystal_GND24; Crystal_SMD_Abracon_ABM3B-4pin_5.0x3.2mm

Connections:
+3.3VA: L6.2, L7.2, R35.1, U5.8 (V+), U6.8 (V+), U16.8 (V+); also elsewhere on the board
+3V3: L8.1, L9.1; also elsewhere on the board
+5V: U7.8 (V+), U8.8 (V+); also elsewhere on the board
-5V: U7.4 (V-), U8.4 (V-); also elsewhere on the board
/audio/LIN1: C59.1, R44.2, U4.17 (LLINEIN)
/audio/LIN2: C61.1, R46.2, U3.17 (LLINEIN)
/audio/LOUT1: R70.1, TP30.1, U4.11 (LOUT)
/audio/LOUT2: R74.1, TP32.1, U3.11 (LOUT)
/audio/RIN1: C60.1, R45.2, U4.16 (RLINEIN)
/audio/RIN2: C62.1, R47.2, U3.16 (RLINEIN)
/audio/ROUT1: R71.1, TP31.1, U4.12 (ROUT)
/audio/ROUT2: R75.1, TP33.1, U3.12 (ROUT)
CONN1: R36.1; also elsewhere on the board
CONN2: R37.1; also elsewhere on the board
CONN3: R38.1; also elsewhere on the board
CONN4: R39.1; also elsewhere on the board
CONN9: R56.2; also elsewhere on the board
CONN10: R57.2; also elsewhere on the board
CONN11: R58.2; also elsewhere on the board
CONN12: R59.2; also elsewhere on the board
GNDA: C27.2, C28.2, C29.2, C30.2, C35.2, C36.2, C37.2, C38.2, C59.2, C60.2, C61.2, C62.2, R49.2, U3.14 (AGND), U3.21 (PAD), U4.14 (AGND), U4.21 (PAD), U5.4 (V-), U6.4 (V-), U16.4 (V-), U16.5 (+), U16.6 (-); also elsewhere on the board
I2C0_SCL: U4.19 (SCLK); also elsewhere on the board
I2C0_SDA: U4.18 (SDIN); also elsewhere on the board
I2C1_SCL: U3.19 (SCLK); also elsewhere on the board
I2C1_SDA: U3.18 (SDIN); also elsewhere on the board
I2S0_RX_SCK: U4.6 (BCLK); also elsewhere on the board
I2S0_RX_SDA: U4.7 (PBDAT); also elsewhere on the board
I2S0_RX_WS: U4.8 (PBLRC); also elsewhere on the board
I2S0_TX_SDA: U4.9 (RECDAT); also elsewhere on the board
I2S0_TX_WS: U4.10 (RECLRC); also elsewhere on the board
I2S1_RX_SCK: U3.6 (BCLK); also elsewhere on the board
I2S1_RX_SDA: U3.7 (PBDAT); also elsewhere on the board
I2S1_RX_WS: U3.8 (PBLRC); also elsewhere on the board
I2S1_TX_SDA: U3.9 (RECDAT); also elsewhere on the board
I2S1_TX_WS: U3.10 (RECLRC); also elsewhere on the board
unnamed: C23.1, U3.1 (MCLK/XTI), Y2.1
unnamed: C24.1, U4.1 (MCLK/XTI), Y3.1
unnamed: C25.1, U3.2 (XTO), Y2.3
unnamed: C26.1, U4.2 (XTO), Y3.3
unnamed: C27.1, C29.1, L6.1, U3.13 (AVDD)
unnamed: C28.1, C30.1, L7.1, U4.13 (AVDD)
unnamed: C31.1, C33.1, L8.2, U3.4 (DVDD)
unnamed: C32.1, C34.1, L9.2, U4.4 (DVDD)
unnamed: R28.2, U5.3 (+)
unnamed: R30.2, U5.5 (+)
unnamed: R32.2, U6.3 (+)
unnamed: R34.2, U6.5 (+)
unnamed: R35.2, R49.1, U16.3 (+)
unnamed: R36.2, R40.1, U5.2 (-)
unnamed: R37.2, R41.1, U5.6 (-)
unnamed: R38.2, R42.1, U6.2 (-)
unnamed: R39.2, R43.1, U6.6 (-)
unnamed: R40.2, R44.1, TP18.1, U5.1
unnamed: R41.2, R45.1, TP19.1, U5.7
unnamed: R42.2, R46.1, TP20.1, U6.1
unnamed: R43.2, R47.1, TP21.1, U6.7
unnamed: R48.2, U7.3 (+)
unnamed: R50.2, U7.5 (+)
unnamed: R52.1, R70.2, U7.2 (-)
unnamed: R52.2, R56.1, U7.1
unnamed: R53.1, R71.2, U7.6 (-)
unnamed: R53.2, R57.1, U7.7
unnamed: R54.1, R74.2, U8.2 (-)
unnamed: R54.2, R58.1, U8.1
unnamed: R55.1, R75.2, U8.6 (-)
unnamed: R55.2, R59.1, U8.7
unnamed: R64.2, U8.3 (+)
unnamed: R66.2, U8.5 (+)
VMID1: C36.1, C38.1, U4.15 (VMID)
VMID2: C35.1, C37.1, U3.15 (VMID)
VREF: R28.1, R30.1, R32.1, R34.1, R48.1, R50.1, R64.1, R66.1, U16.1, U16.2 (-); also elsewhere on the board

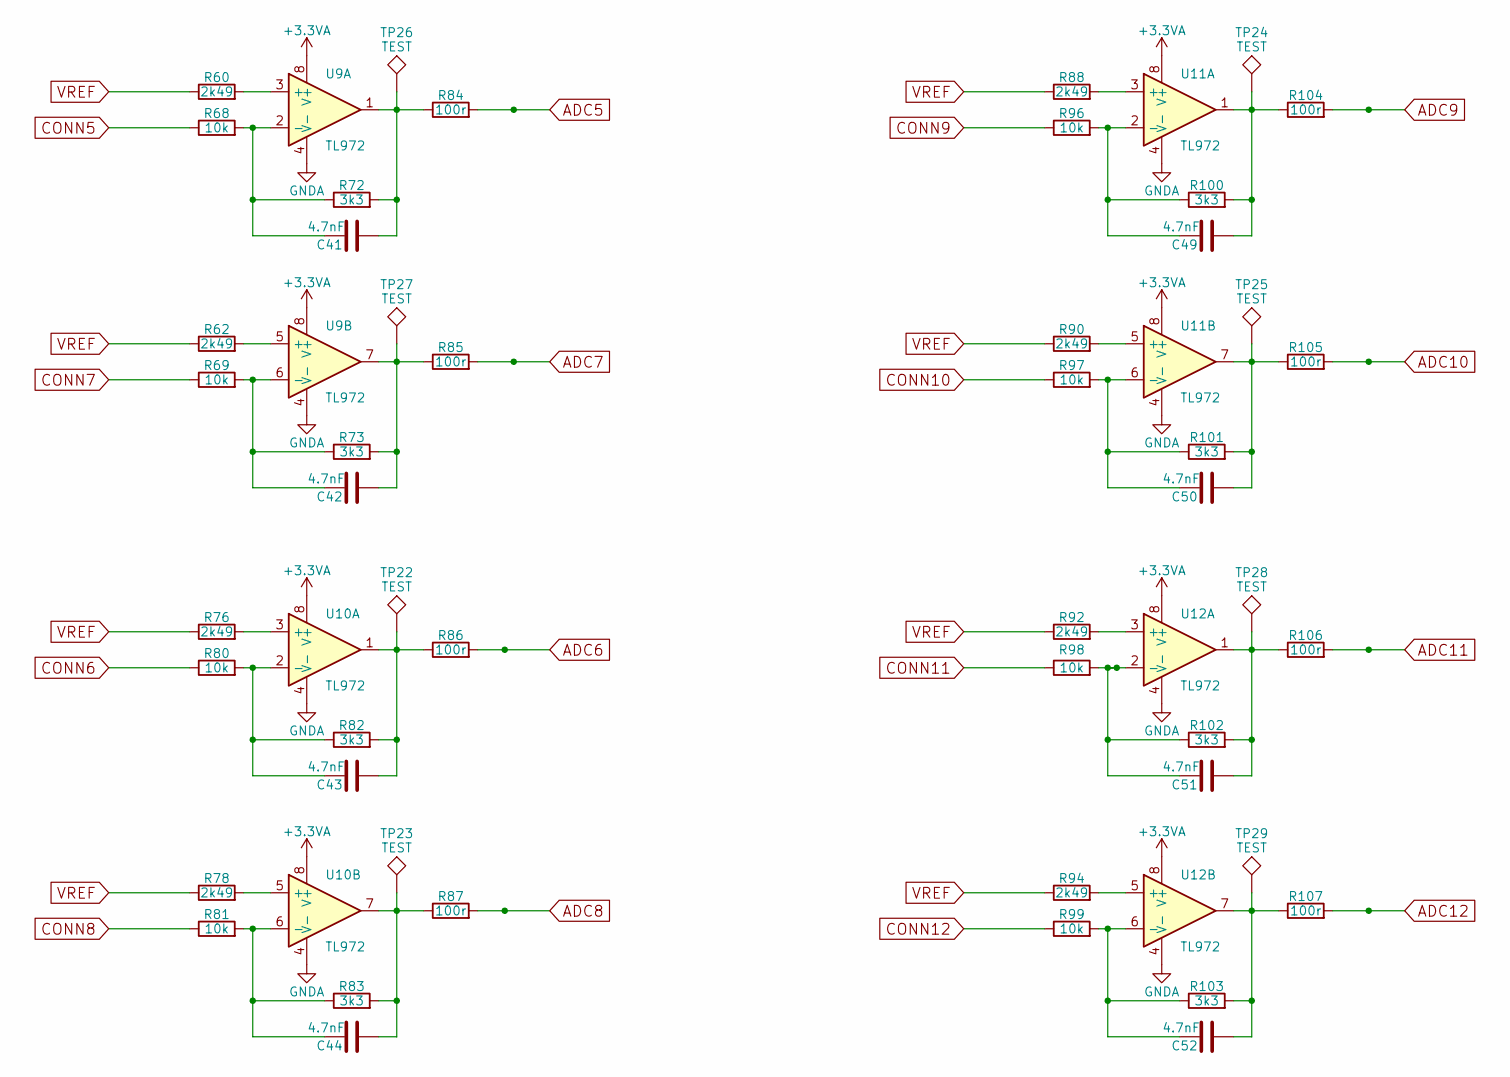
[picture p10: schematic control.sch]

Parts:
C41, C42, C43, C44, C49, C50, C51, C52: 4.7nF; C_0603
R60, R62, R76, R78, R88, R90, R92, R94: 2k49; R_0603
R68, R69, R80, R81, R96, R97, R98, R99: 10k; R_0603
R72, R73, R82, R83, R100, R101, R102, R103: 3k3; R_0603
R84, R85, R86, R87, R104, R105, R106, R107: 100r; R_0603
TP22, TP23, TP24, TP25, TP26, TP27, TP28, TP29: TEST; Measurement_Point_Round-SMD-Pad_Small
U9, U10, U11, U12: TL972; SOIC-8_3.9x4.9mm_Pitch1.27mm

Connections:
+3.3VA: U9.8 (V+), U10.8 (V+), U11.8 (V+), U12.8 (V+); also elsewhere on the board
ADC5: R84.2; also elsewhere on the board
ADC6: R86.2; also elsewhere on the board
ADC7: R85.2; also elsewhere on the board
ADC8: R87.2; also elsewhere on the board
ADC9: R104.2; also elsewhere on the board
ADC10: R105.2; also elsewhere on the board
ADC11: R106.2; also elsewhere on the board
ADC12: R107.2; also elsewhere on the board
CONN5: R68.1; also elsewhere on the board
CONN6: R80.1; also elsewhere on the board
CONN7: R69.1; also elsewhere on the board
CONN8: R81.1; also elsewhere on the board
CONN9: R96.1; also elsewhere on the board
CONN10: R97.1; also elsewhere on the board
CONN11: R98.1; also elsewhere on the board
CONN12: R99.1; also elsewhere on the board
GNDA: U9.4 (V-), U10.4 (V-), U11.4 (V-), U12.4 (V-); also elsewhere on the board
unnamed: C41.1, R72.2, R84.1, TP26.1, U9.1
unnamed: C41.2, R68.2, R72.1, U9.2 (-)
unnamed: C42.1, R73.2, R85.1, TP27.1, U9.7
unnamed: C42.2, R69.2, R73.1, U9.6 (-)
unnamed: C43.1, R82.2, R86.1, TP22.1, U10.1
unnamed: C43.2, R80.2, R82.1, U10.2 (-)
unnamed: C44.1, R83.2, R87.1, TP23.1, U10.7
unnamed: C44.2, R81.2, R83.1, U10.6 (-)
unnamed: C49.1, R100.2, R104.1, TP24.1, U11.1
unnamed: C49.2, R96.2, R100.1, U11.2 (-)
unnamed: C50.1, R101.2, R105.1, TP25.1, U11.7
unnamed: C50.2, R97.2, R101.1, U11.6 (-)
unnamed: C51.1, R102.2, R106.1, TP28.1, U12.1
unnamed: C51.2, R98.2, R102.1, U12.2 (-)
unnamed: C52.1, R103.2, R107.1, TP29.1, U12.7
unnamed: C52.2, R99.2, R103.1, U12.6 (-)
unnamed: R60.2, U9.3 (+)
unnamed: R62.2, U9.5 (+)
unnamed: R76.2, U10.3 (+)
unnamed: R78.2, U10.5 (+)
unnamed: R88.2, U11.3 (+)
unnamed: R90.2, U11.5 (+)
unnamed: R92.2, U12.3 (+)
unnamed: R94.2, U12.5 (+)
VREF: R60.1, R62.1, R76.1, R78.1, R88.1, R90.1, R92.1, R94.1; also elsewhere on the board

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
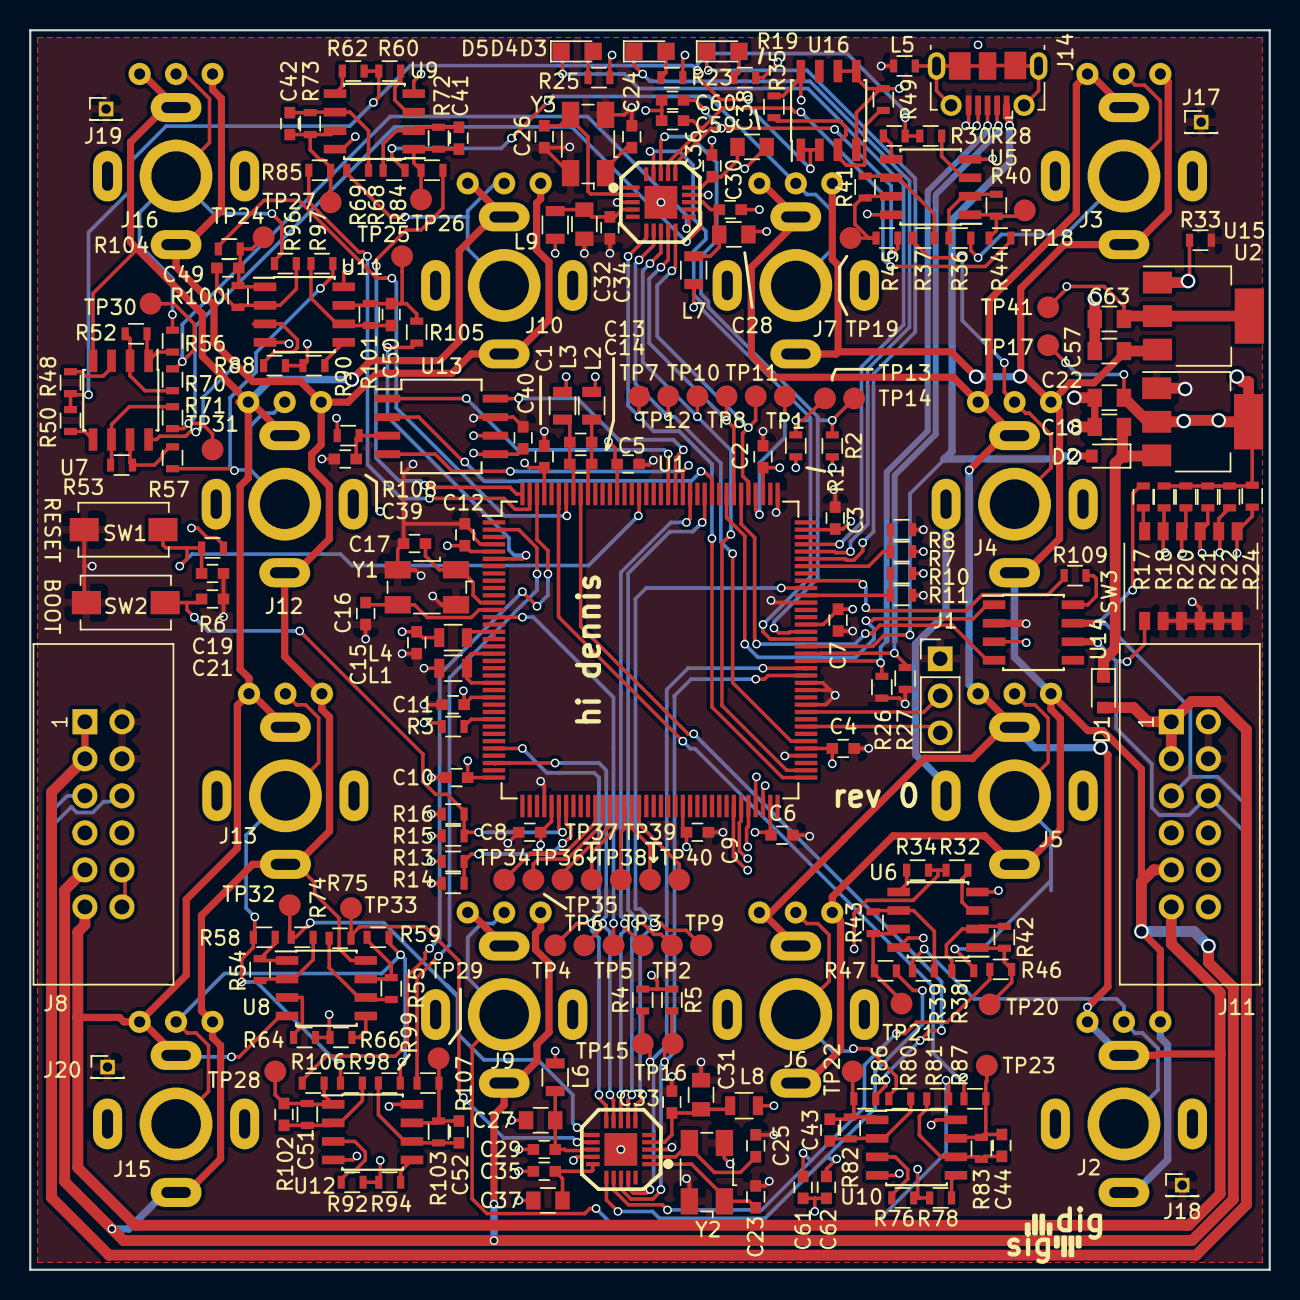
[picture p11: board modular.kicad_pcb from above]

Board: 4 copper layers, 85.0 x 85.0 mm, 244 parts (0 on the bottom side), 160 nets.

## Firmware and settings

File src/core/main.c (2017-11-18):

#include <string.h>
#include <math.h>

#include "chip.h"

#include "adc.h"
#include "mon.h"
#include "evq.h"
#include "can.h"
#include "usb.h"
#include "timer.h"
#include "cmd.h"
#include "flash.h"
#include "i2s.h"
#include "led.h"
#include "printd.h"
#include "uart.h"
#include "uda1380.h"
#include "watchdog.h"
#include "ssm2604.h"
#include "button.h"
#include "shared.h"
#include "mod.h"
#include "ifft.h"
#include "dpy.h"

#define LPC_OTP ((LPC_OTP_T *) LPC_OTP_BASE)
	
uint32_t mod_id = 0;

const uint32_t OscRateIn = 12000000;
const uint32_t ExtRateIn = 0;

struct cmd_cli cli = {
	.tx = NULL,
	.echo = true,
};


void arch_init(void)
{
	Chip_SetupCoreClock(CLKIN_CRYSTAL, MAX_CLOCK_FREQ, true);
	Chip_Clock_SetBaseClock(CLK_BASE_USB1, CLKIN_IDIVD, true, true);

	/* We seem to need a delay for clocks to come up otherwise USB won't
	 * work? */

	volatile int i;
	for(i=0; i<100000; i++);
}


static void to_shared_log(uint8_t c)
{
	shared->log.buf[shared->log.head] = c;
	shared->log.head = (shared->log.head + 1) % SHARED_LOG_BUF_SIZE;
}


static void logd(const char *fmt, ...)
{
	va_list va;
	va_start(va, fmt);
	vfprintd(to_shared_log, fmt, va);
	va_end(va);
}




/*
 * This function is called by the M4; it is defined here to allow
 * RAM1 to be updated with new code while the M4 waits here until
 * finished. Blink the blue led like crazy until we can go on
 */

void main(void)
{
	uint32_t id = LPC_OTP->OTP0_2;
	if(id == 0x24b14191) mod_id = 1;
	if(id == 0x1ab14191) mod_id = 2;
	if(id == 0x26c94191) mod_id = 3;

	memset((void *)shared, 0, sizeof(*shared));
	shared->logd = logd;

	arch_init();
	watchdog_init();
	led_init();
	button_init();
	uart_init();

	printd_set_handler(uart_tx);
	printd("\n\nHello %s %s %s %08x\n", VERSION, __DATE__, __TIME__);

	timer_init();
	usb_init(mod_id);

	flash_init();
	adc_init();
	i2s_init(SRATE);
	ssm2604_init();
	can_init(500000, mod_id); /* Must be done after I2C/ADC setup, see errata 3.2 */
	dpy_init();
	mon_init();
		
	NVIC_EnableIRQ(M4_IRQn);

	logd("M0 ready %08x\n", id);

	if(mod_id == 1) mod_load_name("vco");
	if(mod_id == 2) mod_load_name("vcf");
	if(mod_id == 3) mod_load_name("reverb");

	for(;;) {
		event_t ev;
		evq_wait(&ev);
		watchdog_poll();
	}
}


void M4_IRQHandler(void)
{
	Chip_CREG_ClearM4Event();
	event_t ev;
	ev.type = EV_M4;
	evq_push(&ev);
}

static void on_ev_m4(event_t *ev, void *data)
{
	if(shared->log.tail != shared->log.head) {
		printd("\e[36m");
		while(shared->log.tail != shared->log.head) {
			printd("%c", shared->log.buf[shared->log.tail]);
			shared->log.tail = (shared->log.tail + 1) % SHARED_LOG_BUF_SIZE;
		}
		printd("\e[0m");
	}
}

	

EVQ_REGISTER(EV_M4, on_ev_m4);



static void on_ev_usbcli(event_t *ev, void *data)
{
	size_t i;
	cli.tx = usb_clipipe_tx;
	for(i=0; i<ev->usbcli.len; i++) {
		cmd_cli_handle_char(&cli, ev->usbcli.data[i]);
	}
}

EVQ_REGISTER(EV_USBCLI, on_ev_usbcli);


static void on_ev_uart(event_t *ev, void *data)
{
	cli.tx = uart_tx;
	uint8_t c = ev->uart.data;
	cmd_cli_handle_char(&cli, c);
}

EVQ_REGISTER(EV_UART, on_ev_uart);


static void on_ev_tick_10hz(event_t *ev, void *data)
{
	static int m = false;
	led_set(LED_ID_GREEN, m ? LED_STATE_ON : LED_STATE_OFF);
	m = !m;
}

EVQ_REGISTER(EV_TICK_10HZ, on_ev_tick_10hz);


static int on_cmd_reboot(struct cmd_cli *cli, uint8_t argc, char **argv)
{
	watchdog_reboot();
	return 1;
}


CMD_REGISTER(reboot, on_cmd_reboot, "");


static int on_cmd_version(struct cmd_cli *cli, uint8_t argc, char **argv)
{
	cmd_printd(cli, "modular %s / %s / %s %s\n", VERSION, BUILD, __DATE__, __TIME__);
	return 1;
}

CMD_REGISTER(version, on_cmd_version, "");


static int on_cmd_clock(struct cmd_cli *cli, uint8_t argc, char **argv)
{
	if(argc == 1) {
		uint32_t rate = strtol(argv[0], NULL, 0) * 1000000;
		if(rate >= 8000000 && rate <= 204000000) {
			Chip_SetupCoreClock(CLKIN_CRYSTAL, rate, true);
		}
	}
	
	cmd_printd(cli, "%d\n", Chip_Clock_GetMainPLLHz());
	return 1;
}


CMD_REGISTER(clock, on_cmd_clock, "");


static int on_cmd_log(struct cmd_cli *cli, uint8_t argc, char **argv)
{
	cmd_hexdump(cli, (void *)shared->log.buf, SHARED_LOG_BUF_SIZE, 0);
	return 1;
}

CMD_REGISTER(log, on_cmd_log, "");

/*
 * End
 */

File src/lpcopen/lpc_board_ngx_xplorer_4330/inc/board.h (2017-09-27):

/*
 * @brief NGX Xplorer 4330 board file
 *
 * @note
 * Copyright(C) NXP Semiconductors, 2013
 * All rights reserved.
 *
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
 * @par
 * Permission to use, copy, modify, and distribute this software and its
 * documentation is hereby granted, under NXP Semiconductors' and its
 * licensor's relevant copyrights in the software, without fee, provided that it
 * is used in conjunction with NXP Semiconductors microcontrollers.  This
 * copyright, permission, and disclaimer notice must appear in all copies of
 * this code.
 */

#ifndef __BOARD_H_
#define __BOARD_H_

#include "chip.h"
/* board_api.h is included at the bottom of this file after DEBUG setup */

#ifdef __cplusplus
extern "C" {
#endif

/** @defgroup BOARD_NGX_XPLORER_4330 LPC4330 NGX Xplorer board support software API functions
 * @ingroup LPCOPEN_43XX_BOARD_NGX4330
 * The board support software API functions provide some simple abstracted
 * functions used across multiple LPCOpen board examples. See @ref BOARD_COMMON_API
 * for the functions defined by this board support layer.<br>
 * @{
 */

/** @defgroup BOARD_NGX_XPLORER_4330_OPTIONS BOARD: LPC4330 NGX Xplorer board options
 * This board has options that configure its operation at build-time.<br>
 * @{
 */

/** Define DEBUG_ENABLE to enable IO via the DEBUGSTR, DEBUGOUT, and
    DEBUGIN macros. If not defined, DEBUG* functions will be optimized
	out of the code at build time.
 */
#define DEBUG_ENABLE

/** Define DEBUG_SEMIHOSTING along with DEBUG_ENABLE to enable IO support
    via semihosting. You may need to use a C library that supports
	semihosting with this option.
 */
//#define DEBUG_SEMIHOSTING

/** Board UART used for debug output and input using the DEBUG* macros. This
    is also the port used for Board_UARTPutChar, Board_UARTGetChar, and
	Board_UARTPutSTR functions. */
#define DEBUG_UART LPC_USART0

/**
 * @}
 */

/* Board name */
#define BOARD_NGX_XPLORER_4330











/* Build for RMII interface */
#define USE_RMII
#define BOARD_ENET_PHY_ADDR	0x01



#define I2CDEV_UDA1380_ADDR     (0x34 >> 1)
#define UDA1380_I2C_BUS          I2C0

/* For USBLIB examples */
#define LEDS_LED1           0x01
#define LEDS_LED2           0x02
#define LEDS_LED3           0x04
#define LEDS_LED4           0x08
#define LEDS_NO_LEDS        0x00
#define BUTTONS_BUTTON1     0x01
#define JOY_UP              0x01
#define JOY_DOWN            0x02
#define JOY_LEFT            0x04
#define JOY_RIGHT           0x08
#define JOY_PRESS           0x10
#define NO_BUTTON_PRESSED   0x00

/*Define if use SDCARD for Mass Storage Example*/
// #define CFG_SDCARD

#define BUTTONS_BUTTON1_GPIO_PORT_NUM   0
#define BUTTONS_BUTTON1_GPIO_BIT_NUM    7
#define LED1_GPIO_PORT_NUM              1
#define LED1_GPIO_BIT_NUM               11
#define LED2_GPIO_PORT_NUM              1
#define LED2_GPIO_BIT_NUM               12

/**
 * @brief	Sets up board specific I2C interface
 * @param	id	: I2C Peripheral ID (I2C0, I2C1)
 * @return	Nothing
 */
void Board_I2C_Init(I2C_ID_T id);

/**
 * @brief	Sets up I2C Fast Plus mode
 * @param	id	: Must always be I2C0
 * @return	Nothing
 * @note	This function must be called before calling
 *          Chip_I2C_SetClockRate() to set clock rates above
 *          normal range 100KHz to 400KHz. Only I2C0 supports
 *          this mode.
 */
STATIC INLINE void Board_I2C_EnableFastPlus(I2C_ID_T id)
{
	Chip_SCU_I2C0PinConfig(I2C0_FAST_MODE_PLUS);
}

/**
 * @brief	Disable I2C Fast Plus mode and enables default mode
 * @param	id	: Must always be I2C0
 * @return	Nothing
 * @sa		Board_I2C_EnableFastPlus()
 */
STATIC INLINE void Board_I2C_DisableFastPlus(I2C_ID_T id)
{
	Chip_SCU_I2C0PinConfig(I2C0_STANDARD_FAST_MODE);
}

/**
 * @brief	Initializes board specific GPIO Interrupt
 * @return	Nothing
 */
void Board_GPIO_Int_Init(void);

/**
 * @brief	Initialize pin muxing for SSP interface
 * @param	pSSP	: Pointer to SSP interface to initialize
 * @return	Nothing
 */
void Board_SSP_Init(LPC_SSP_T *pSSP);

/**
 * @brief	Returns the MAC address assigned to this board
 * @param	mcaddr : Pointer to 6-byte character array to populate with MAC address
 * @return	Nothing
 */
void Board_ENET_GetMacADDR(uint8_t *mcaddr);

/**
 * @brief	Initialize pin muxing for a UART
 * @param	pUART	: Pointer to UART register block for UART pins to init
 * @return	Nothing
 */
void Board_UART_Init(LPC_USART_T *pUART);

/**
 * @brief	Initialize pin muxing for SDMMC interface
 * @return	Nothing
 */
void Board_SDMMC_Init(void);

/**
 * @brief	Initialize button(s) interface on board
 * @return	Nothing
 */
void Board_Buttons_Init(void);

/**
 * @brief	Initialize joystick interface on board
 * @return	Nothing
 */
void Board_Joystick_Init(void);

/**
 * @brief	Returns joystick states on board
 * @return	Returns a JOY_* value, ir JOY_PRESS or JOY_UP
 */
uint8_t Joystick_GetStatus(void);

/**
 * @brief	Returns button(s) state on board
 * @return	Returns BUTTONS_BUTTON1 if button1 is pressed
 */
uint32_t Buttons_GetStatus (void);
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

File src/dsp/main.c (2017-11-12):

#include <string.h>
#include <stdlib.h>
#include <math.h>

#include "chip.h"
#include "module.h"
#include "ctl.h"
#include "../core/shared.h"


static void update_state(void);
static void update_led(void);

enum module_mode module_mode = MODULE_MODE_FLOAT;

void M0APP_IRQHandler(void)
{
	Chip_CREG_ClearM0AppEvent();
}


static void update_level(int i, int32_t v)
{
	if(v > shared->level[i].max) shared->level[i].max = v;
	if(v < shared->level[i].min) shared->level[i].min = v;
}


static const float scale_i2s = 1.0 / 32768.0;
static float inv_ticks_per_sample = 1000 * SRATE / 204e6;
void (*logd)(const char *str, ...);

static volatile float gain = 1.0;

static union sample {
	int16_t s16[2];
	uint32_t u32;
} s;


void I2S0_IRQHandler(void)
{
	uint32_t t1 = SysTick->VAL;

	if(Chip_I2S_GetRxLevel(LPC_I2S0) >= 2) {
		uint32_t v = Chip_I2S_Receive(LPC_I2S0);
		shared->in[0] = v >> 16;
		shared->in[1] = v & 0xffff;
	}

	if(Chip_I2S_GetRxLevel(LPC_I2S1) >= 2) {
		uint32_t v = Chip_I2S_Receive(LPC_I2S1);
		shared->in[2] = v >> 16;
		shared->in[3] = v & 0xffff;
	}

	if(mod.run_float) {
		float fin[12];
		float fout[4] = { 0 };

		fin[ 0] = -shared->in[ 0] * scale_i2s;
		fin[ 1] = -shared->in[ 1] * scale_i2s;
		fin[ 2] = -shared->in[ 2] * scale_i2s;
		fin[ 3] = -shared->in[ 3] * scale_i2s;
		fin[ 4] =  shared->in[ 4] * scale_i2s;
		fin[ 5] =  shared->in[ 5] * scale_i2s;
		fin[ 6] =  shared->in[ 6] * scale_i2s;
		fin[ 7] =  shared->in[ 7] * scale_i2s;
		fin[ 8] =  shared->in[ 8] * scale_i2s;
		fin[ 9] =  shared->in[ 9] * scale_i2s;
		fin[10] =  shared->in[10] * scale_i2s;
		fin[11] =  shared->in[11] * scale_i2s;

		mod.run_float(fin, fout);

		shared->out[0] = fout[0] * gain;
		shared->out[1] = fout[1] * gain;
		shared->out[2] = fout[2] * gain;
		shared->out[3] = fout[3] * gain;
	}
	
	if(mod.run_int16) {
		mod.run_int16((int16_t *)shared->in, (int16_t *)shared->out);
	}

	if(Chip_I2S_GetTxLevel(LPC_I2S0) < 4) {
		s.s16[0] = shared->out[1];
		s.s16[1] = shared->out[0];
		Chip_I2S_Send(LPC_I2S0, s.u32);
	}
	if(Chip_I2S_GetTxLevel(LPC_I2S1) < 4) {
		s.s16[0] = shared->out[3];
		s.s16[1] = shared->out[2];
		Chip_I2S_Send(LPC_I2S1, s.u32);
	}

	if(shared->scope.src && shared->scope.n < SHARED_SCOPE_SIZE) {
		shared->scope.buf[shared->scope.n++] = *shared->scope.src;
	}
		
	uint32_t t2 = SysTick->VAL;
	shared->m4_load = ((int32_t)t1-(int32_t)t2) * inv_ticks_per_sample;
}


void main(void)
{
	if(mod.init) {
		mod.init();
	}

	logd = shared->logd;

	logd("M4 ready\n");
	if(mod.name) {
		logd("mod '%s'\n", mod.name);
	}
	SysTick->CTRL = SysTick_CTRL_CLKSOURCE_Msk | SysTick_CTRL_ENABLE_Msk;
	SysTick->LOAD = 0x00ffffffu;
	
	NVIC_EnableIRQ(I2S0_IRQn);

	for(;;) {

		__DMB();
		__WFI();

		if(mod.run_bg) {
			mod.run_bg();
		}

		int i;

		for(i=0; i<4; i++) {
			update_level(i+0, shared->in[i]);
			update_level(i+4, shared->out[i]);
		}

		for(i=0; i<8; i++) {
			update_level(i+8, shared->in[i+4]);
		}


		/* Bookkeeping */

		update_led();
		update_state();
		ctl_poll();
	}

}


static void update_state(void)
{
	/* Handle fade in/out */

	if(shared->m4_state == M4_STATE_FADEIN) {
		if(gain < 32767.0) {
			gain *= 1.0006;
		} else {
			shared->m4_state = M4_STATE_RUNNING;
		}
	} else if(shared->m4_state == M4_STATE_FADEOUT) {
		if(gain > 1.0) {
			gain *= 0.9994;
		} else {
			shared->m4_state = M4_STATE_HALT;
		}
	}

	if(shared->m4_state == M4_STATE_HALT) {
		NVIC_DisableIRQ(I2S0_IRQn);
		for(;;) {
			__WFI();
			Chip_GPIO_SetPinState(LPC_GPIO_PORT, 1, 11, 0);
		}
	}
}


static void update_led(void)
{
	static const uint8_t breath[] = {
		0, 0, 0, 16, 32, 64, 128, 254, 254, 200, 150, 100, 60, 40, 30,
		30, 60, 120, 240, 230, 200, 170, 140, 110, 90, 70, 50, 40, 30,
		20, 10, 7, 5, 4, 3, 2, 1, 0, 0, 0, 0, 0, 0, 0, 0,
	};

	static size_t i = 0;
	static size_t j = 0;
	static uint8_t v = 0;

	LPC_GPIO_PORT->B[0][14] = (j > v);

	if(++j >= 255) {
		j = 0;
		if(++i >= sizeof(breath)<<3) {
			i = 0;
		}
		v = breath[i >> 3];
	}
}




/*
 * End
 */

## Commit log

2017-09-28 Various; adjusted analog master volume to prevent killing my ears
    [main.c]
2017-09-28 Reworking A/D oversampling and triggering
    [adc.c, main.c]
2017-10-02 Added CDC UART
2017-10-08 Added first revision PCB nad schematics
    [audio.sch, control.sch, modular.kicad_pcb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]
2017-10-09 Before usb differential pair
    [audio.sch, control.sch, modular.kicad_pcb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]
2017-10-09 Added CAN terminator to dip1
    [audio.sch, control.sch, modular.kicad_pcb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]
2017-10-09 connected DIP switches
    [modular.kicad_pcb, modular.sch]
2017-10-09 Added ground fills on top and bottom layer
    [modular.kicad_pcb]
2017-10-11 Added SPI flash
2017-10-11 Added logo and top/bottom planes
    [audio.sch, control.sch, modular.kicad_pcb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]
2017-10-11 Added opamp circuit simulations
2017-10-11 Reworked all analog inputs and outputs
    [audio.sch, control.sch, modular.kicad_pcb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]
2017-10-11 Some last reworks in power through V3.3 net, silkscreen optimization. Ready!
    [modular.kicad_pcb]
2017-10-11 Fixed SPI connections
    [modular.kicad_pcb, modular.sch]
2017-10-12 Simplified passing control from M4 to M0 and back; the M4 is now simply put to reset while the image is loaded.
    [boot.c, main.c]
2017-10-12 More simplifications of M4 reset/wakup
    [main.c]
2017-10-12 Reworked software, added module system
    [main.c]
2017-10-15 Added PWM control to polyblep pulse osc
2017-10-17 Samplerate is now defined in top level Rules.mak -DSRATE=48000
2017-10-17 Added panel drawing in dxf
    [panel-metaal.dxf]
2017-10-18 Moved design up from /doc
    [panel-metaal.dxf]
2017-10-18 Added fade out before stopping m4 for rebooting
    [main.c]
2017-10-19 Fixed steel drawing DXF
    [panel-metaal.dxf]
2017-10-20 Updated LED's mux and gpio settings for new PCB
2017-10-21 Moved hw to hw/rev0
    [audio.sch, bom.odf.ods, control.sch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]
2017-10-22 Use 32 bits transfers at the I2C bus for each sample
2017-10-22 Changed I2S MCLK generator settings to make a clock without jitter because the codec does not like this at all. This limits the available choices for sample rates though, so now we end up at 44270Hz 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
    [ssm2604.c]
2017-10-22 Removed debugging prints from ssm2604.c
2017-10-23 Fixed IRQ table for M0
    [boot.c, main.c]
2017-10-23 Updated fixme for pcb rev0
2017-10-23 Fixed ADC's
2017-10-23 Fixed ADC reading
2017-10-25 Added pitch shift module
2017-10-25 Loading, buttons
2017-10-25 Pitch improvements
2017-10-25 Better M4 load calculation using systick timer
2017-10-26 Replaced prind with float-capable version
    [printd.c]
2017-10-26 Some adc scaling
2017-10-26 Added arm cmsis-dsp lib
2017-10-28 Button now cycles between mods
2017-10-28 Now build with 2016q3 arm compiler, better optimization
2017-10-29 ADC IRQ now writes into shared directly
2017-10-30 Added logd() to shared struct so m4 can write logs; made printd() reentrant
2017-10-30 Build with -Wextra, added __DMB() to fix syncing of shared struct when compiling with O3
    [flash.c, main.c]
2017-10-30 Improved flashing, added verify of SPI transfer
2017-10-31 Fixed sign of adcs/pots
    [main.c]
2017-10-31 Reworked memory layout. Core is now in RAM3 so RAM1 and RAM2 are available for DSP code. Updated reverb to put comb filter buffers in RAM2
    [cdc_uart.c, main.c]
2017-11-01 Added 'g[ain]' command to ssm2604
    [bom.odf.ods]
2017-11-01 Reworked pot/switch binding
2017-11-01 VCO bandlimit switch
2017-11-04 Enabled lowpass in ssa2604 until opamp input circuits are fixed
    [main.c, ssm2604.c]
2017-11-04 Changed I2S word size from 32 to 16 bits. We don't have the accuracy in the ADC/DAC to get below 16 bits anyway
2017-11-04 Fixed M4 load calculation range
    [main.c]
2017-11-07 Update CAN cli refresh timer
2017-11-10 Reworked USB: there are now separte endpoints for MIDI and the clipipe, allowing proper 8-bit safe bulk transfers for flashing without needing to do all kidn of nasty sysex handling
    [main.c]
2017-11-11 Reworked stuff to use evq
    [adc.c, board.h, can.c]
2017-11-12 Switched CAN bitrate from 250 to 1000 kbit
2017-11-18 small stuff, can bitrate is now 500 because 1000 is problematic
    [can.c, main.c]
